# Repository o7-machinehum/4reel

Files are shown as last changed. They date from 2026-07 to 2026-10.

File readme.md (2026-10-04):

# 4reel
4reel is a platform for robots that don't have enough computing power to run machine vision algorithms. It's capable of stereo depth processing, image classification and SLAM.

When connected over USB-C the device will present itself as an Ethernet adapter and DHCP you an IP address, configuration can be done on the web portal at `http://192.168.77.1:8080/`

The JST connecter can be used to send data UART to an Arduino, ESP32, etc. The same JST conncetor can be used to power the device with 5V.
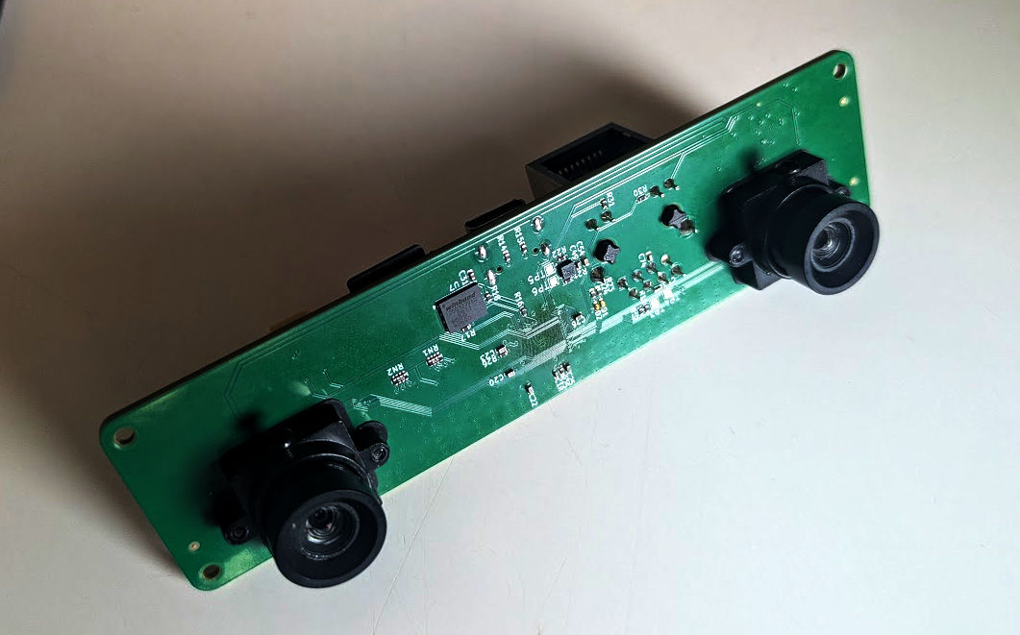
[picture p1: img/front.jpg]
Main image

## System Overview

4reel RV1103 board block diagram

## Repo structure
``` bash
.
|-- img
|-- os
|-- readme.md
|-- ref
|-- rv1103    # Current tested board
|-- rv1106    # Next generation
`-- scripts   # Automation scripts I wrote
```

# Media
- https://youtube.com/shorts/XkLzl0wEfN4?si=KPXePSXCayTTsI1j

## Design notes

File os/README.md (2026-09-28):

# 4reel OS

Buildroot-based Linux image for the 4reel boards (RV1103 and RV1106).

```sh
git submodule update --init
cd buildroot
make BR2_EXTERNAL=$PWD/../ rv1103g_defconfig
make
```

The SD-card image is written to `os/buildroot/output/images/sdcard.img`.

Linux and U-Boot use standalone configs in `board/rv1103g/{linux,uboot}_defconfig`.
After menuconfig changes, save them with `make linux-update-defconfig` or
`make uboot-update-defconfig`. Omit the machine-specific
`CONFIG_ENV_DEFAULT_ENV_TEXT_FILE` line from the saved U-Boot config; Buildroot
sets it from `uboot.env`.

The device-hosted camera dashboard is at `http://192.168.77.1:8080/`;
[calibration instructions](board/rv1103g/WEB_DEPTH.md) cover its first depth map.

On the RV1103G board, USB-C presents a network adapter to the host. The host
gets an address via DHCP; connect with `ssh root@192.168.77.1`. Root logs in
without a password in this development image.

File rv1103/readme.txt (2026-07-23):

Ovrdrive
--------
Size :	36.6 x 15 mm
Layer : 4 Layers
Material : FR-4: TG150
Thickness : 1.6 mm nominal (PCBWay regular 4-layer construction)
Min track/spacing : 4/4mil
Min hole size : 0.2mm
Solder mask : Black
Silkscreen : White
Edge connector : No
Surface finish : HASL lead free
Via process : Tenting vias
Finished copper : 1 oz Cu (Inner Copper:1 oz)
Remove product No. : Yes

PCBWay regular 4-layer stackup (nominal 1.6 mm)
-------------------------------------------------
Selected construction: PCBWay "4-layers PCB Regular" with 1 oz finished
outer copper and 1 oz inner copper.

Top to bottom:
L1 Cu : 0.5 oz base copper, plated to 1 oz finished (~0.035 mm)
PP    : 7628 RC46%, Dk 4.7, 0.1855 mm after lamination
L2 Cu : 1 oz (0.035 mm), continuous GND reference plane
Core  : Dk 4.6, 1.0300 mm dielectric (1.1 mm including L2/L3 copper)
L3 Cu : 1 oz (0.035 mm), continuous GND reference plane
PP    : 7628 RC46%, Dk 4.7, 0.1855 mm after lamination
L4 Cu : 0.5 oz base copper, plated to 1 oz finished (~0.035 mm)

PCBWay lists this construction at approximately 1.51 mm finished thickness,
with +/-10% tolerance, ordered as nominal 1.6 mm.

100 ohm differential Ethernet routing
--------------------------------------
Geometry: edge-coupled microstrip on L1/L4, referenced to the adjacent GND plane
Target differential impedance : 100 ohm +/-10%
Trace width                   : 0.160 mm (6.30 mil)
Pair gap, edge-to-edge         : 0.125 mm (4.92 mil)
Reference-plane height         : 0.1855 mm
Finished outer copper          : approximately 0.035 mm
Dielectric constant used       : 4.7

IPC/Wadell closed-form estimate without solder mask: approximately 101 ohm
differential. Solder mask, actual material properties, copper shape, and PCBWay
process compensation are not included in that estimate. Order the PCB with
100 ohm differential impedance control and allow PCBWay to adjust the production
width/gap after their field-solver review.

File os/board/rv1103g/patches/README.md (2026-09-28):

# Pending upstream support

Buildroot applies these queues through `BR2_GLOBAL_PATCH_DIR`, in filename
order, after extracting each source tree.

## Linux

The pinned Rockchip 6.1 source already contains the RV1103/RV1106 clock,
pinctrl, and device-tree support. The Linux patch queue only adds board-required
behavior missing from that vendor tree. `linux/linux.hash` verifies the pinned
source archive and its license files.

The board patches make the left-camera rotation persistent and make CIF scale
capture start its sensor/CSI source without full-resolution memory DMA.
RV1103/RV1106 has one shared scaler: the left camera uses it; the right camera
uses normal CSI capture and software downsampling. Both sensors use VC0 on
their separate CSI receivers.
The CMA heap patch supplies the physical-address query and cache synchronization
needed by the RVE SAD backend; physical-address access requires root privileges.

## U-Boot

The U-Boot queue is the complete 15-patch v3 submission with cover
Message-ID `20260707153135.2048115-1-sjg@chromium.org`. It applies to exact
base commit:

```text
ee5d46b45ec0c63f8f9dd1e816e0dac3452ccc3d
```

Keeping the full series preserves the dependencies between the early RV1103B
patches and the later RV1106/RV1103 changes. The RV1103G board DTS, default
environment, and standalone `uboot_defconfig` configure 4reel without loading
the Luckfox defconfig or modifying the submitted patches. The existing
`CONFIG_TARGET_LUCKFOX_PICO_RV1103` selection supplies the shared 64 MiB board
initialization code; the device tree and boot environment are 4reel's.

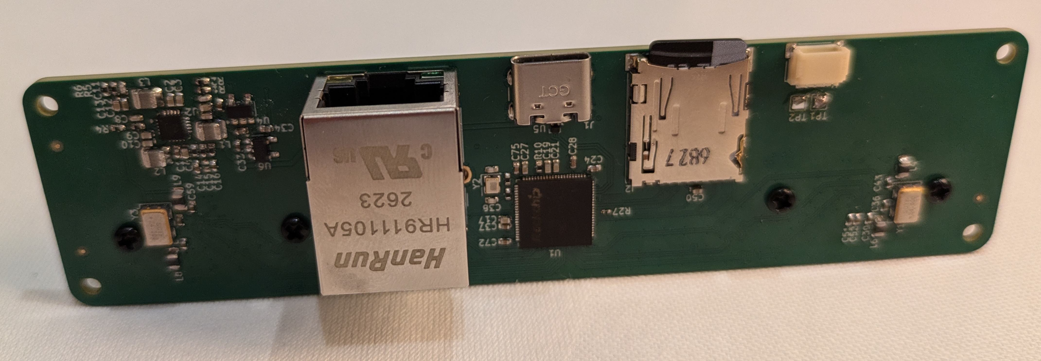
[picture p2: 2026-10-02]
img/back.jpg

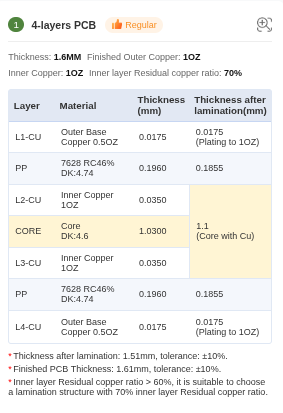
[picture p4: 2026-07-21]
rv1106/stackup.png

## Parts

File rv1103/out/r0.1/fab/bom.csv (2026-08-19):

Designator | Value | Footprint | Quantity | Part Number
C1,C14,C16,C18,C24,C28,C31,C36,C37,C41,C42,C45,C49,C51-C53,C61-C63,C66-C68,C70,C72,C75 | 100nF | Capacitor_SMD:C_0402_1005Metric | 25 | CL05B104KP5VPNC
C2-C5,C7,C9,C10,C12,C13,C17,C19-C23,C25-C27,C50,C54 | 10uF | Capacitor_SMD:C_0402_1005Metric | 20 | GRM155R60J106ME05D
C6,C8,C11 | 220pF | Capacitor_SMD:C_0402_1005Metric | 3 | GCM1555C1H221JA16D
C29,C30,C33-C35,C39,C40,C43,C44,C46-C48,C55-C60,C64,C65,C69,C71 | 1uF | Capacitor_SMD:C_0402_1005Metric | 22 | C0402C105K9PACTU
C32,C38 | 10pF | Capacitor_SMD:C_0402_1005Metric | 2 | GCM1555C1H100JA16D
C73,C74 | 10nF | Capacitor_SMD:C_0402_1005Metric | 2 | C0402C103K5REC7411
D1,D2 | LED | LED_SMD:LED_0402_1005Metric | 2 | LTST-C281KGKT
J1 | USB_C_Receptacle_USB2.0_16P | Connector_USB:USB_C_Receptacle_GCT_USB4105-xx-A_16P_TopMnt_Horizontal | 1 | USB4105-GF-A-120
J2 | Micro_SD_Card_Det2 | Connector_Card:microSD_HC_Hirose_DM3AT-SF-PEJM5 | 1 | DM3AT-SF-PEJM5
J3 | RJ45_Hanrun_HR911105A_Horizontal | Connector_RJ:RJ45_Hanrun_HR911105A_Horizontal | 1 | HR911105A
J4 | JST | Connector_JST:JST_SH_SM04B-SRSS-TB_1x04-1MP_P1.00mm_Horizontal | 1 | SM04B-SRSS-TB
L1-L3 | 1.5uH | Inductor_SMD:L_1008_2520Metric | 3 | DFE252012P-1R5M=P2
L4-L9 | 3u3/0.9A | Inductor_SMD:L_0805_2012Metric | 6 | MLP2012S3R3MT0S1
R1 | 40.2k | Resistor_SMD:R_0402_1005Metric | 1 | RC0402FR-0740K2L
R2 | 9.1k | Resistor_SMD:R_0402_1005Metric | 1 | RC0402FR-079K1L
R3 | 47k | Resistor_SMD:R_0402_1005Metric | 1 | RC0402FR-0747KL
R4,R6,R9 | 100k | Resistor_SMD:R_0402_1005Metric | 3 | RC0402FR-07100KL
R5,R7 | 200k | Resistor_SMD:R_0402_1005Metric | 2 | RC0402FR-07200KL
R8,R17,R18,R26 | 10k | Resistor_SMD:R_0402_1005Metric | 4 | RC0402FR-0710KL
R10 | 240R | Resistor_SMD:R_0402_1005Metric | 1 | RC0402FR-07240RL
R11,R12,R21,R22 | 4.7k | Resistor_SMD:R_0402_1005Metric | 4 | RC0402FR-074K7L
R13,R32 | 0R | Resistor_SMD:R_0402_1005Metric | 2 | RC0402FR-070RL
R14,R15 | 5.6k | Resistor_SMD:R_0402_1005Metric | 2 | RC0402FR-075K6L
R16,R19 | 22R | Resistor_SMD:R_0402_1005Metric | 2 | RC0402FR-0722RL
R20 | 1M | Resistor_SMD:R_0402_1005Metric | 1 | RC0402FR-071ML
R23,R24 | 1k | Resistor_SMD:R_0402_1005Metric | 2 | RC0402FR-071KL
R25 | 6.04k | Resistor_SMD:R_0402_1005Metric | 1 | RC0402FR-076K04L
R27 | 22R | Resistor_SMD:R_0201_0603Metric | 1 | RC0201FR-0722RL
R30,R31 | 330R | Resistor_SMD:R_0402_1005Metric | 2 | RC0402FR-07330RL
RN1,RN2 | 47k | Resistor_SMD:R_Array_Concave_4x0402 | 2 | CAT10-473J4LF
TP3-TP6 | TestPoint | TestPoint:TestPoint_Pad_1.0x1.0mm | 4
U1 | RV1103G | rv1103b:Rockchip_QFN-88-1EP_9x9mm_P0.35mm_EP6.5x6.5mm | 1 | RV1103BG3
U2 | EA3036C | Package_DFN_QFN:QFN-20-1EP_3x3mm_P0.4mm_EP1.65x1.65mm | 1 | EA3036CQBR
U3,U9 | ImageSensor_OV9281 | ov9281:OV9281 | 2 | OV9281
U4 | TLV73312PDBV | Package_TO_SOT_SMD:SOT-23-5 | 1 | TLV73312PDBV
U5 | TPD2EUSB30 | Package_TO_SOT_SMD:Texas_DRT-3 | 1 | TPD2EUSB30ADRTR
U6 | TLV73328PDBV | Package_TO_SOT_SMD:SOT-23-5 | 1 | TLV73328PDBVR
U7 | W25Q32JVZP | Package_SON:WSON-8-1EP_6x5mm_P1.27mm_EP3.4x4.3mm | 1 | W25Q32JVZPIQ
U8 | LIS2HH12 | Package_LGA:LGA-12_2x2mm_P0.5mm | 1 | LIS2HH12TR
Y1,Y3 | TXC-7C | Oscillator:Oscillator_SMD_TXC_7C-4Pin_5.0x3.2mm | 2 | SX5M24.000D20F30TNN
Y2 | 24Mhz | Crystal:Crystal_SMD_2016-4Pin_2.0x1.6mm | 1 | ECS-240-8-37B-CKY-TR

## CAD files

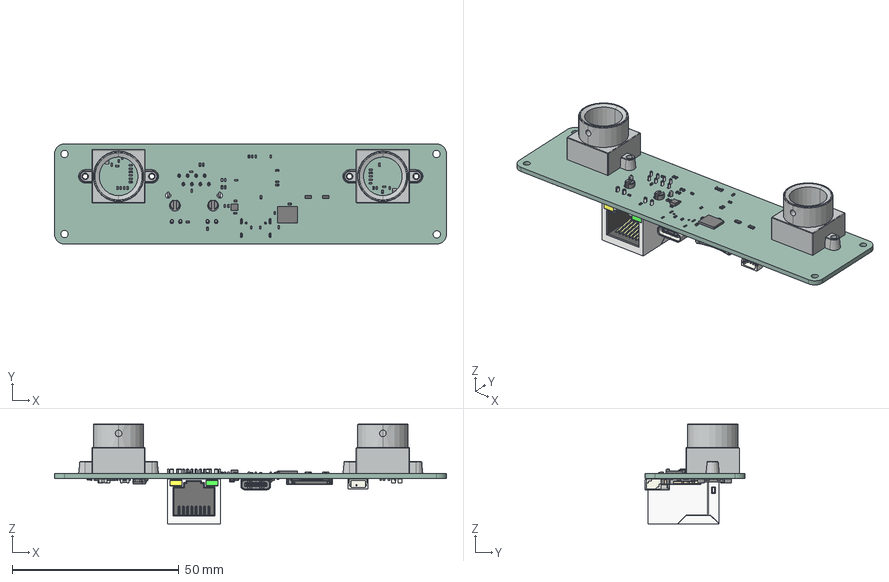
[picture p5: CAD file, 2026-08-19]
rv1103/out/r0.1/4reel_ee.step
117.5 x 30.0 x 29.9 mm
C_0402_1005Metric x 75
R_0402_1005Metric x 29
R_Array_Concave_4x0402 x 2
WSON-8-1EP_6x5mm_P1.27mm_EP3.4x4.3mm
LED_0402_1005Metric x 2
L_0805_2012Metric x 6
LGA_12_2x2mm_P05mm
M12 lens holder x 2
UQFN-20-1EP_3x3mm_Pitch0.4mm
C9D27868-9601-4F3A-8DEA-EF1FE52F23CF
L_1008_2520Metric x 3
SOT-23-5 x 2
R_0201_0603Metric
39AA0248-C475-4DC6-9496-78D43884E41A
Crystal_SMD_2016-4Pin_2.0x1.6mm
USB_C_Receptacle_16P_TopMnt_Horizontal_GCT_USB4105-xx-A
DRT_3
microSD_HC_Hirose_DM3AT-SF-PEJM5
JST_SH_SM04B-SRSS-TB_1x04-1MP_P1.00mm_Horizontal
4reel_ee_PCB

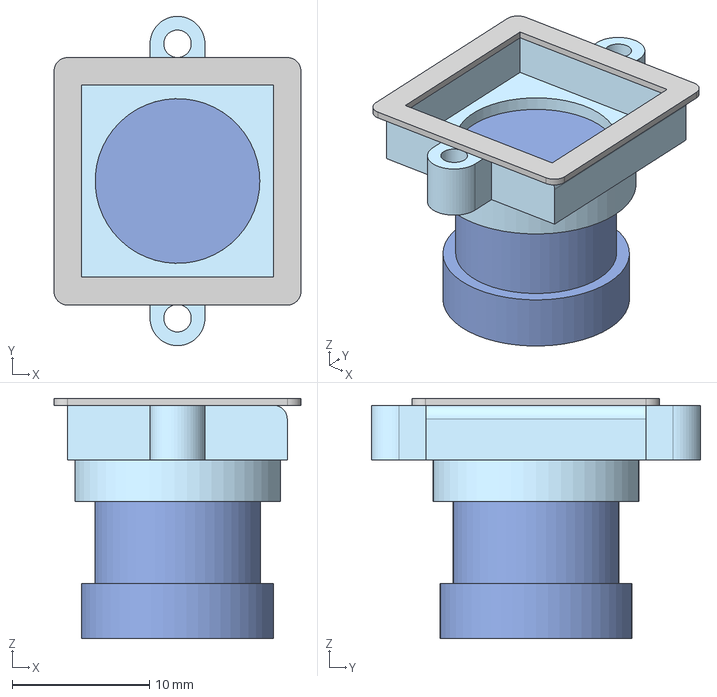
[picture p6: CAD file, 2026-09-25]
rv1103/step/Arducam_U0756.step
18.0 x 24.0 x 17.5 mm

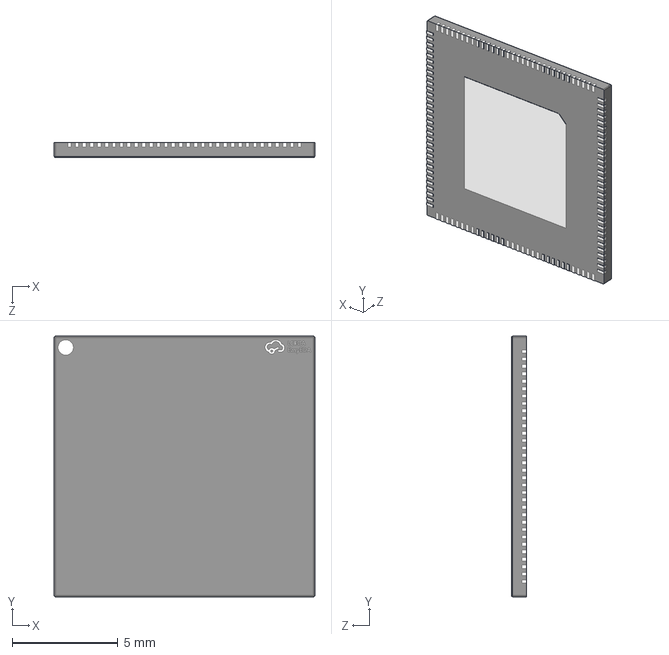
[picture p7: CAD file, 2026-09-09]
rv1106/step/QFN-128_L12.3-W12.3-P0.35-TL-EP7.0-1.step
12.3 x 12.3 x 0.73 mm

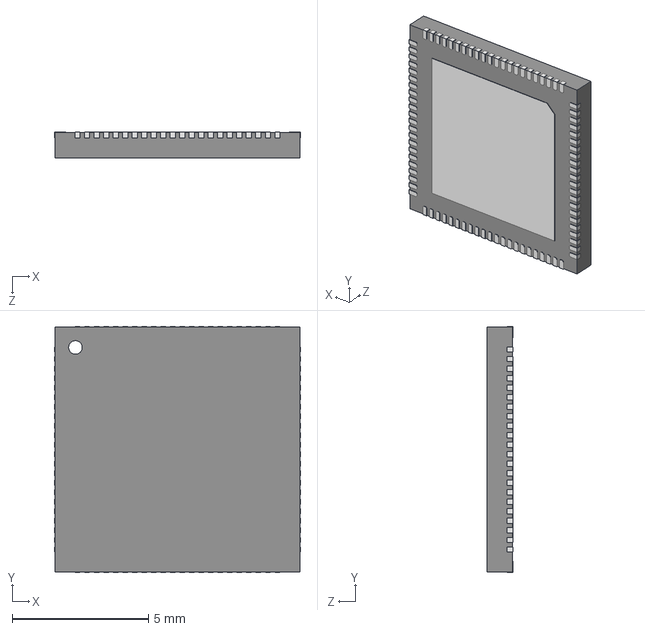
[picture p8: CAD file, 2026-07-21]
rv1106/step/QFN-88P35_EP.step
9.04 x 9.04 x 0.97 mm

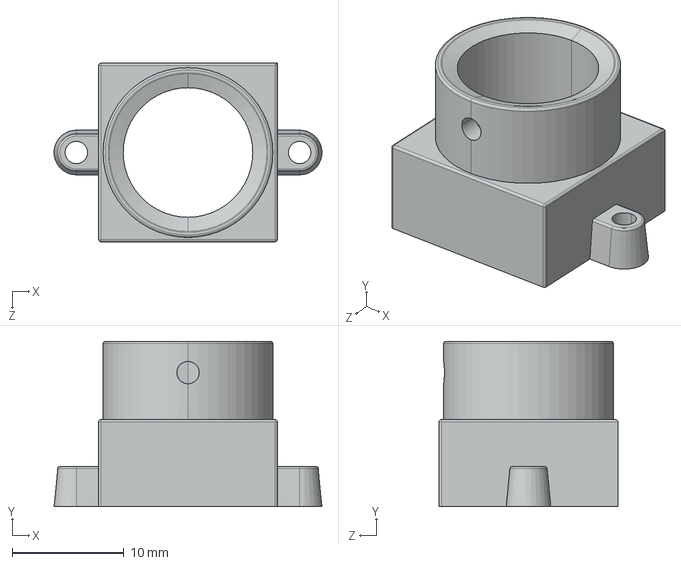
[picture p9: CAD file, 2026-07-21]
rv1103/step/M12_lens_holder.STEP
24.0 x 14.8 x 16.0 mm

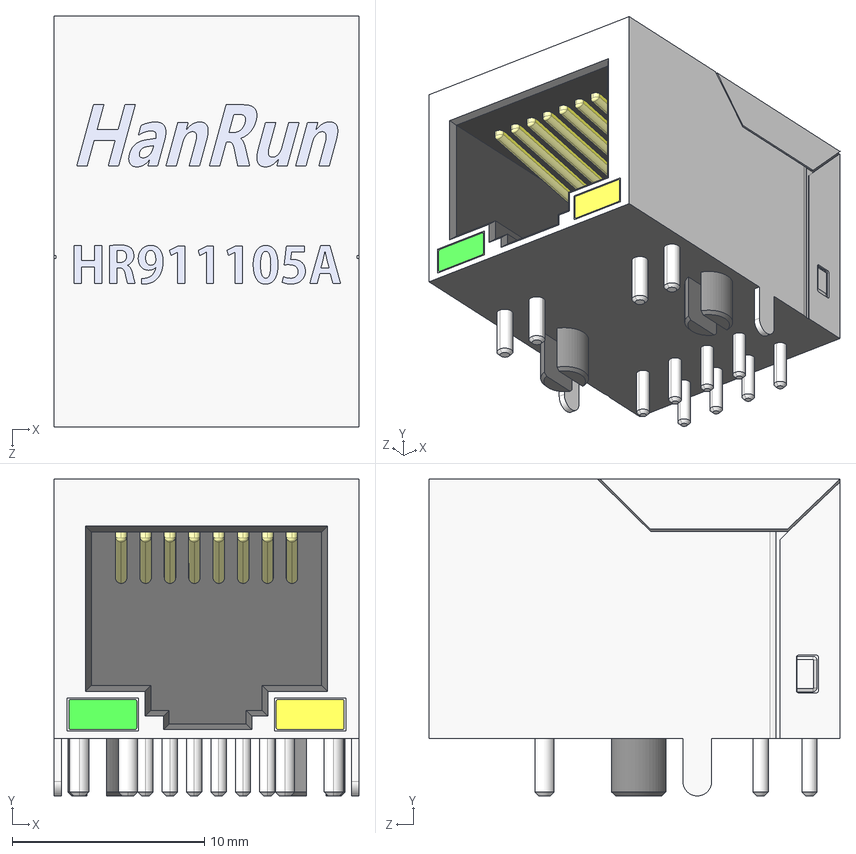
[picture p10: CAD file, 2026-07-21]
rv1106/step/HR911105A.step
15.9 x 16.5 x 21.4 mm

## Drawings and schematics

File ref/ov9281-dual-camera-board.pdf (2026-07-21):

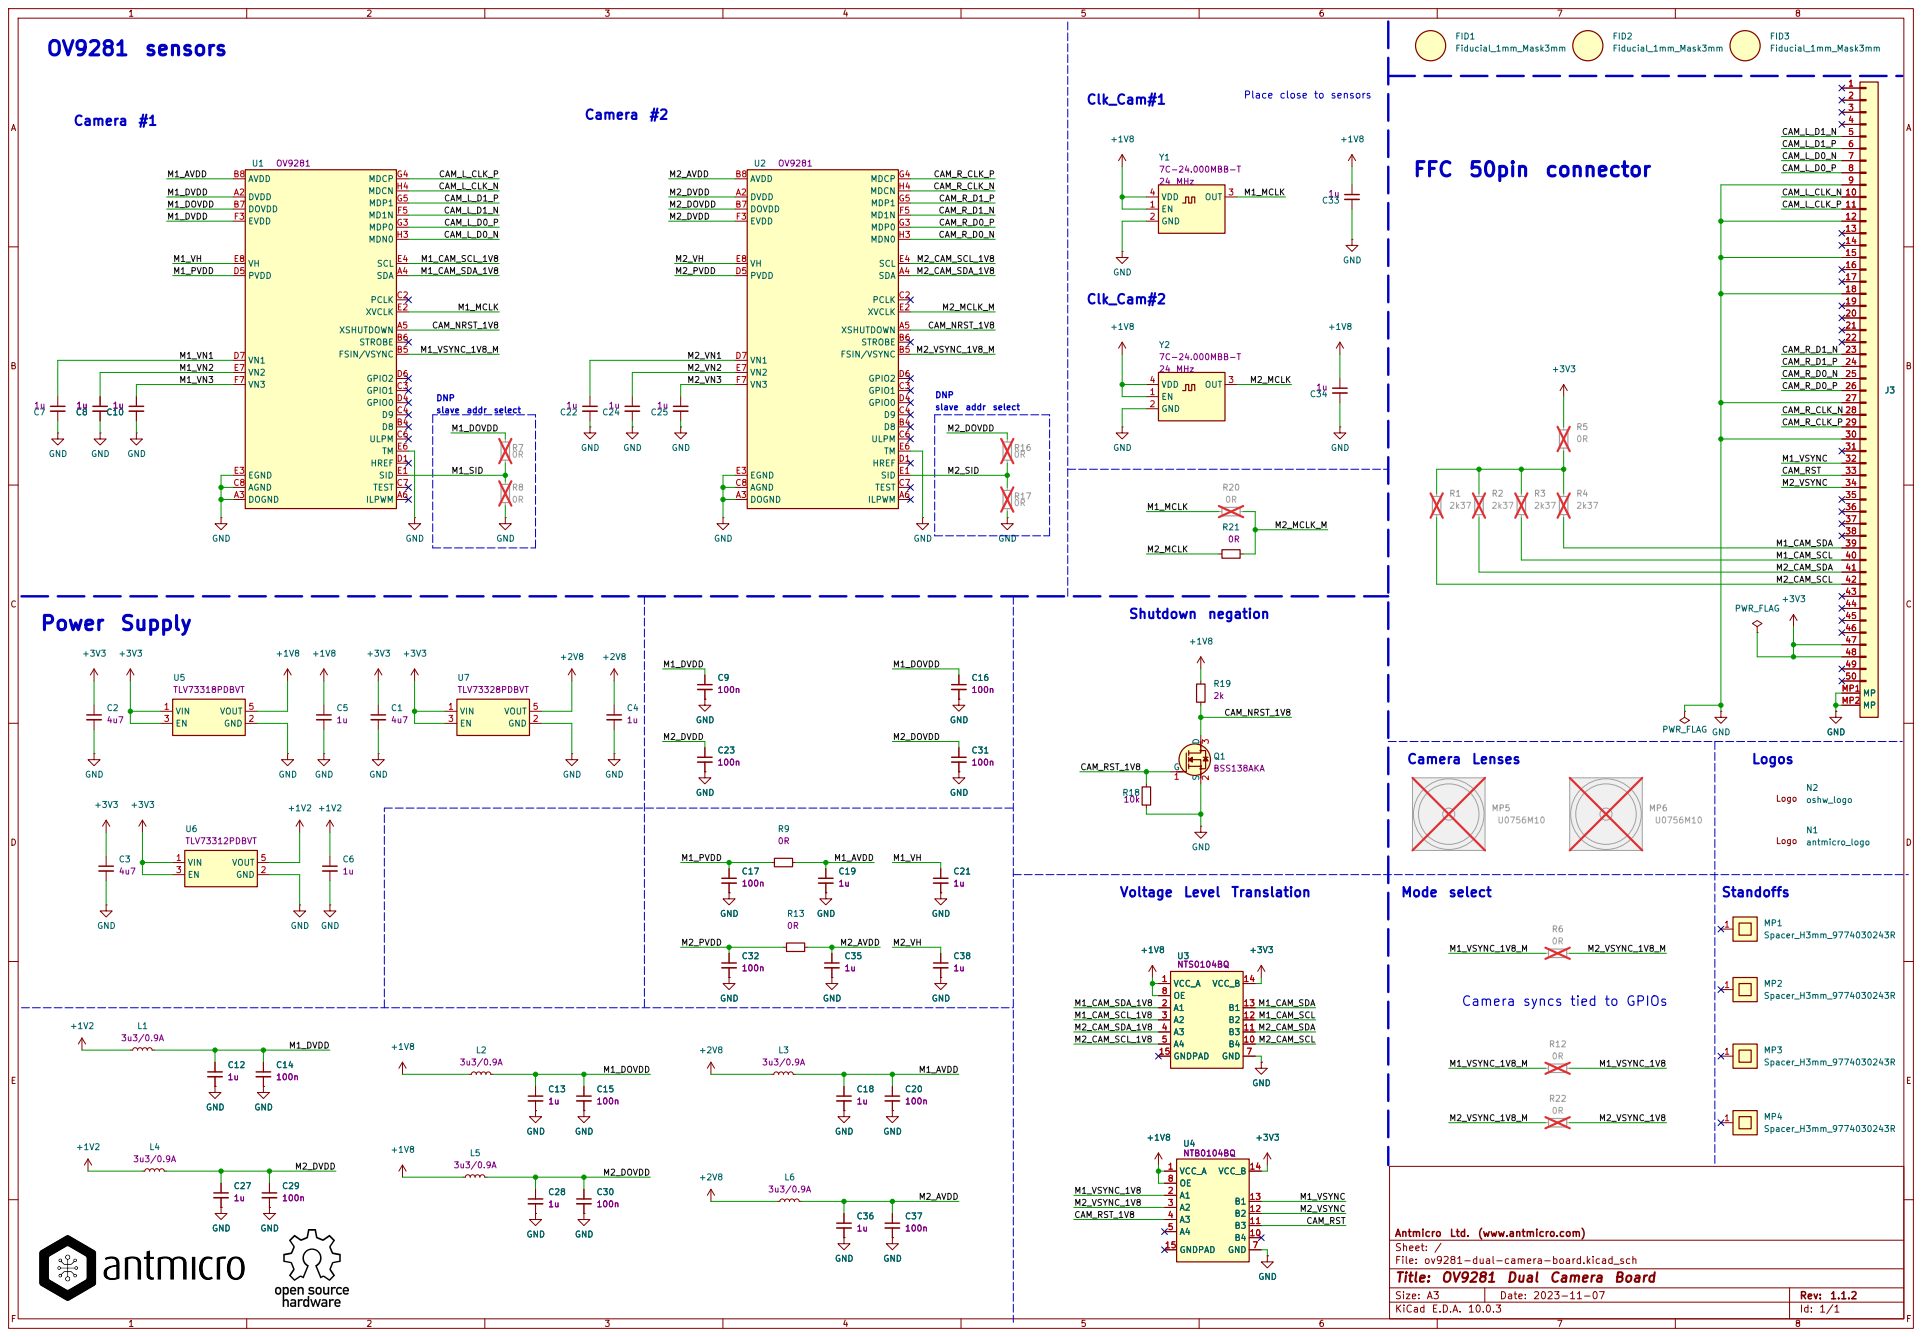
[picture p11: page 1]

Place close to sensors

DVDD A2 DOGND A3
FSIN/VSYNC B5 STROBE B6 DOVDD B7

J3 DVDD A2 DOGND A3

Shutdown negation Power Supply

Camera syncs tied to GPIOs

Antmicro Ltd. (www.antmicro.com) GND

Sheet: /
File: ov9281-dual-camera-board.kicad_sch
Title: OV9281 Dual Camera Board

Size: A3 | Rev: 1.1.2 | F Date: 2023-11-07
KiCad E.D.A. 10.0.3 | Id: 1/1

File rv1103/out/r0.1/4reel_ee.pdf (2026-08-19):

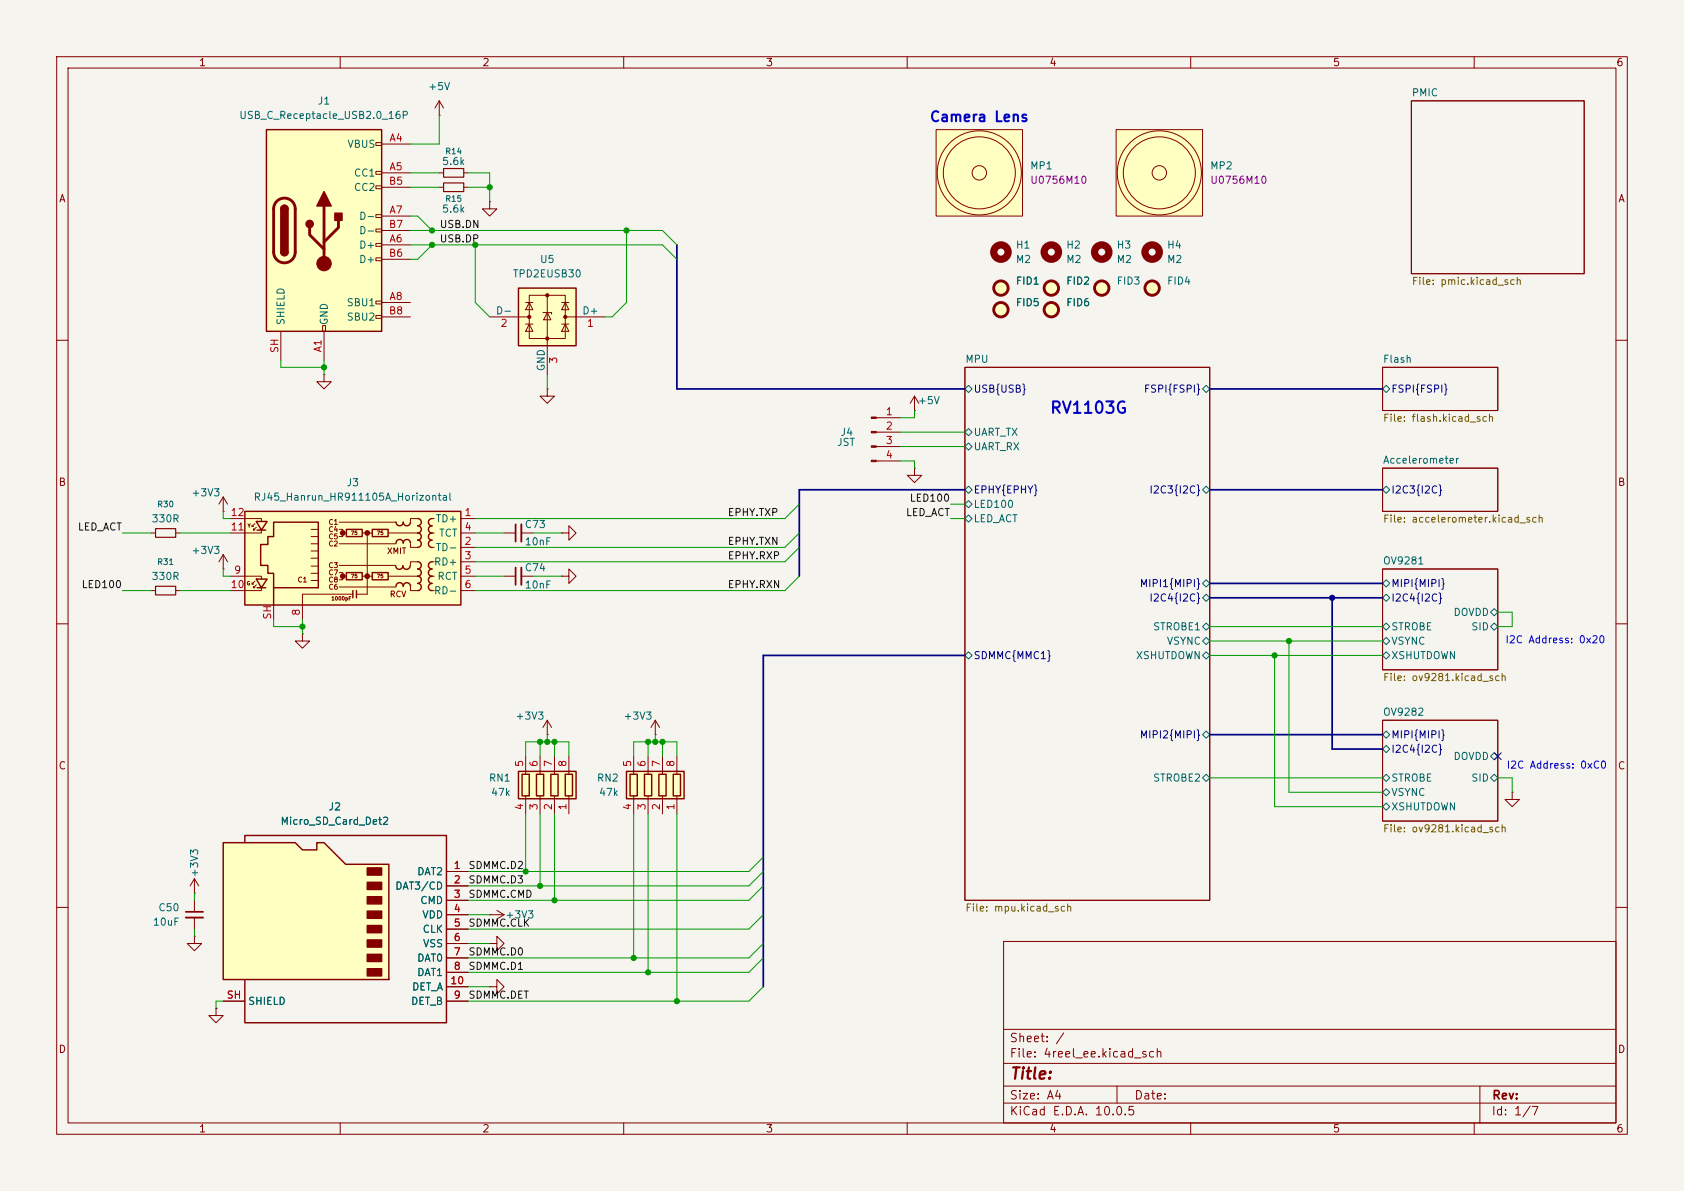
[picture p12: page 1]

I2C3{I2C} Accelerometer File: accelerometer.kicad_sch PMIC

Size: A4 | Rev:
KiCad E.D.A. 10.0.5 | Id: 1/7

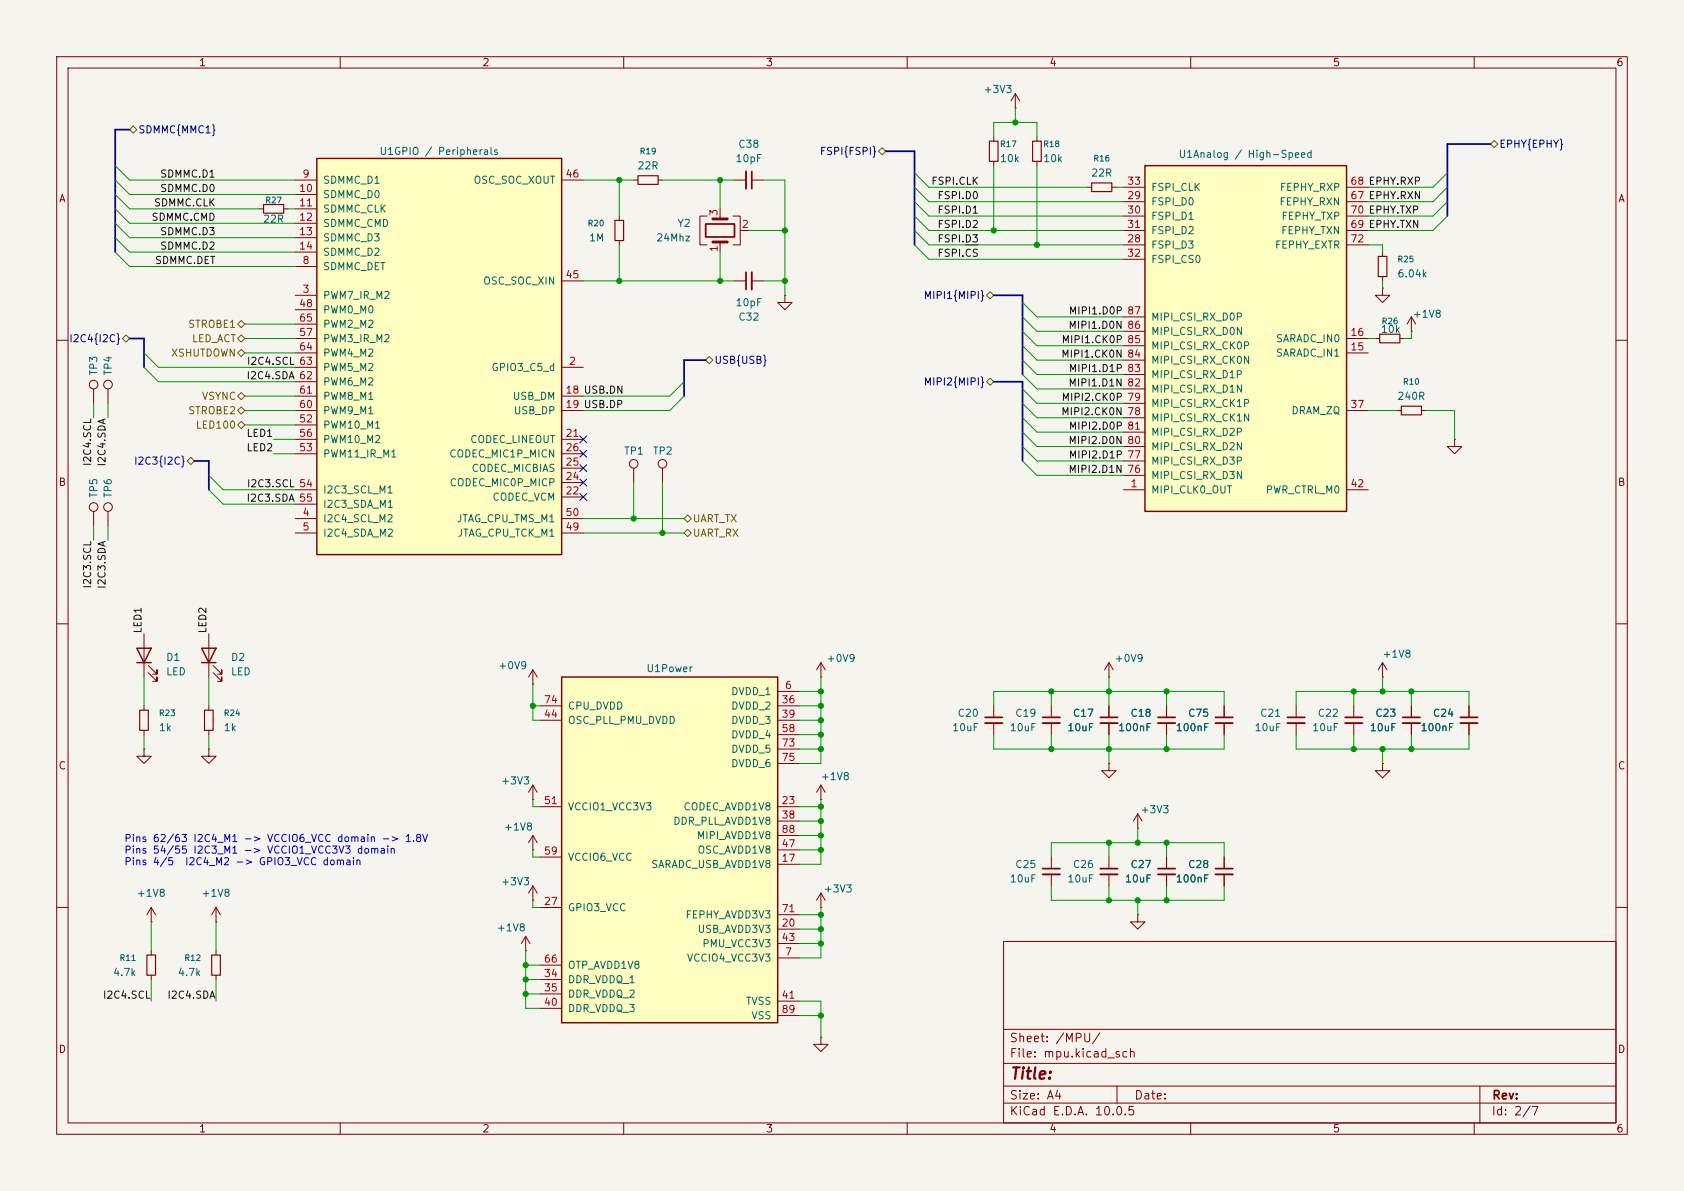
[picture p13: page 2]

SDMMC.DET SDMMC.CLK
SDMMC.CMD

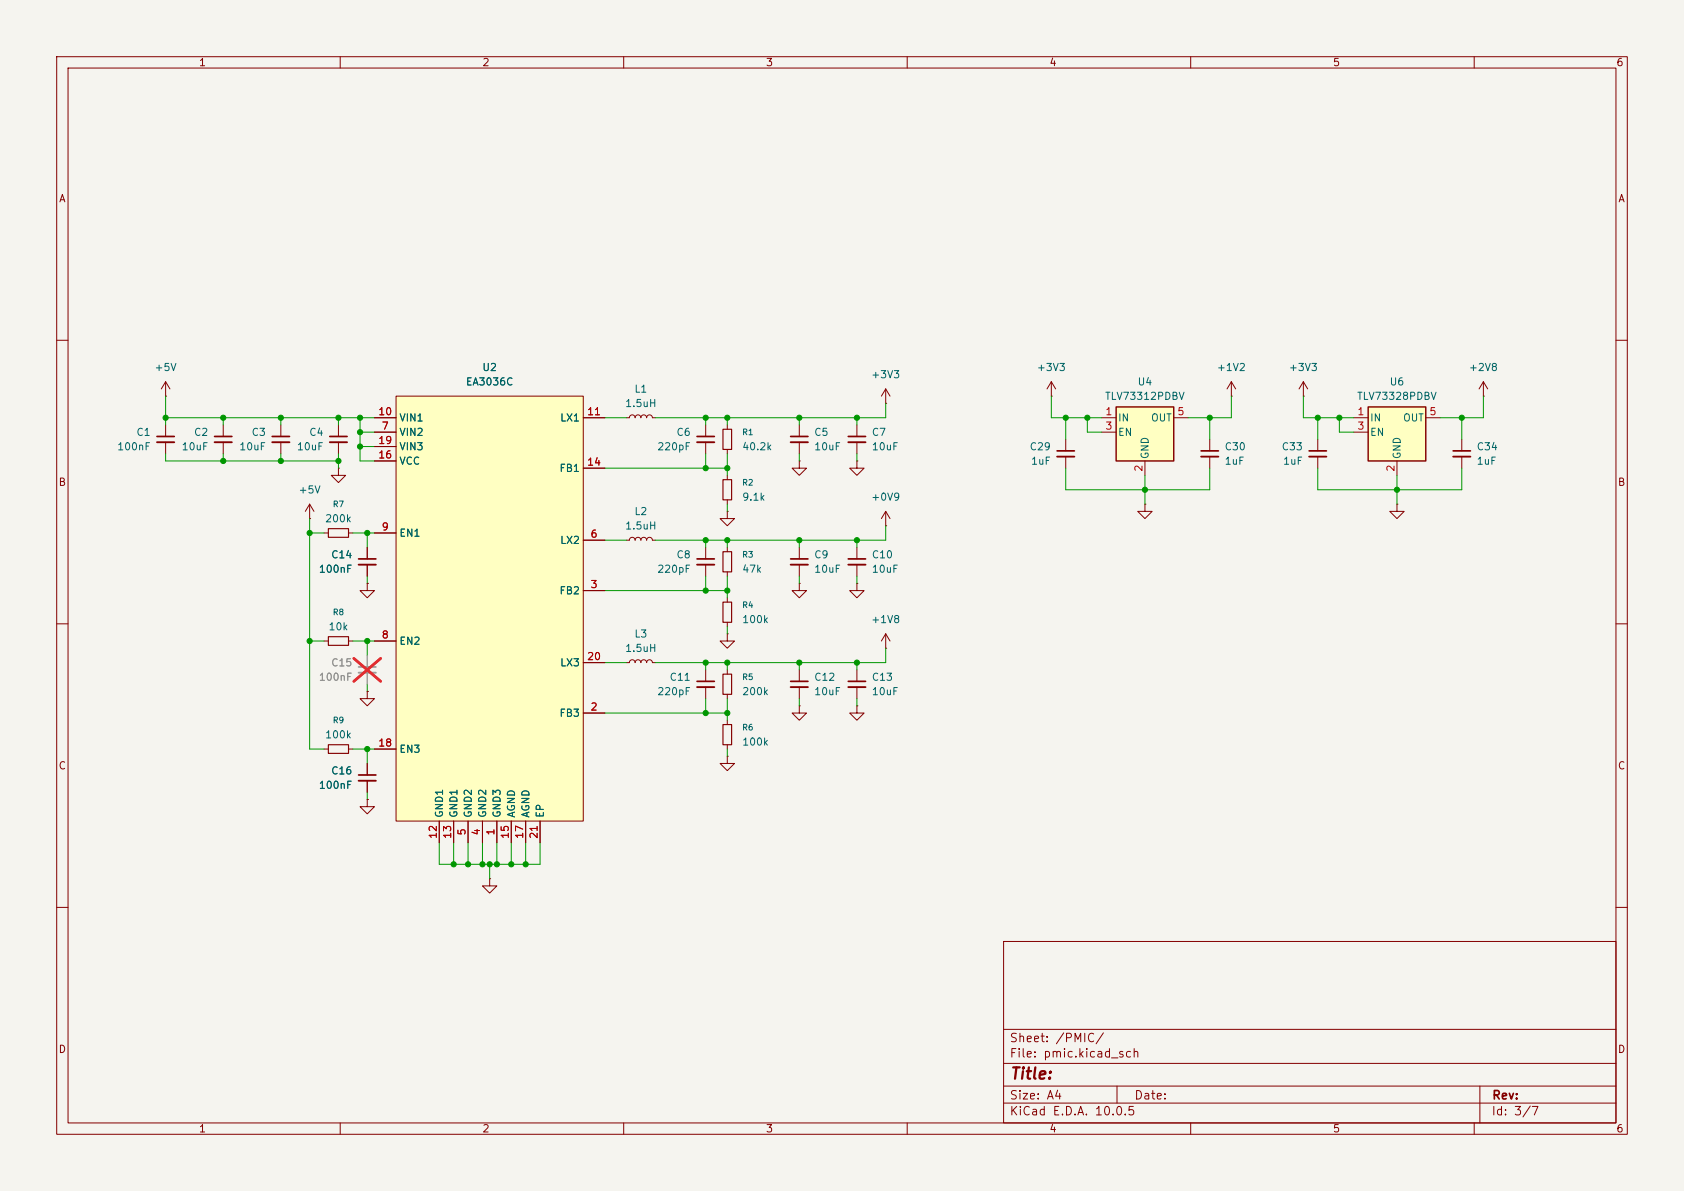
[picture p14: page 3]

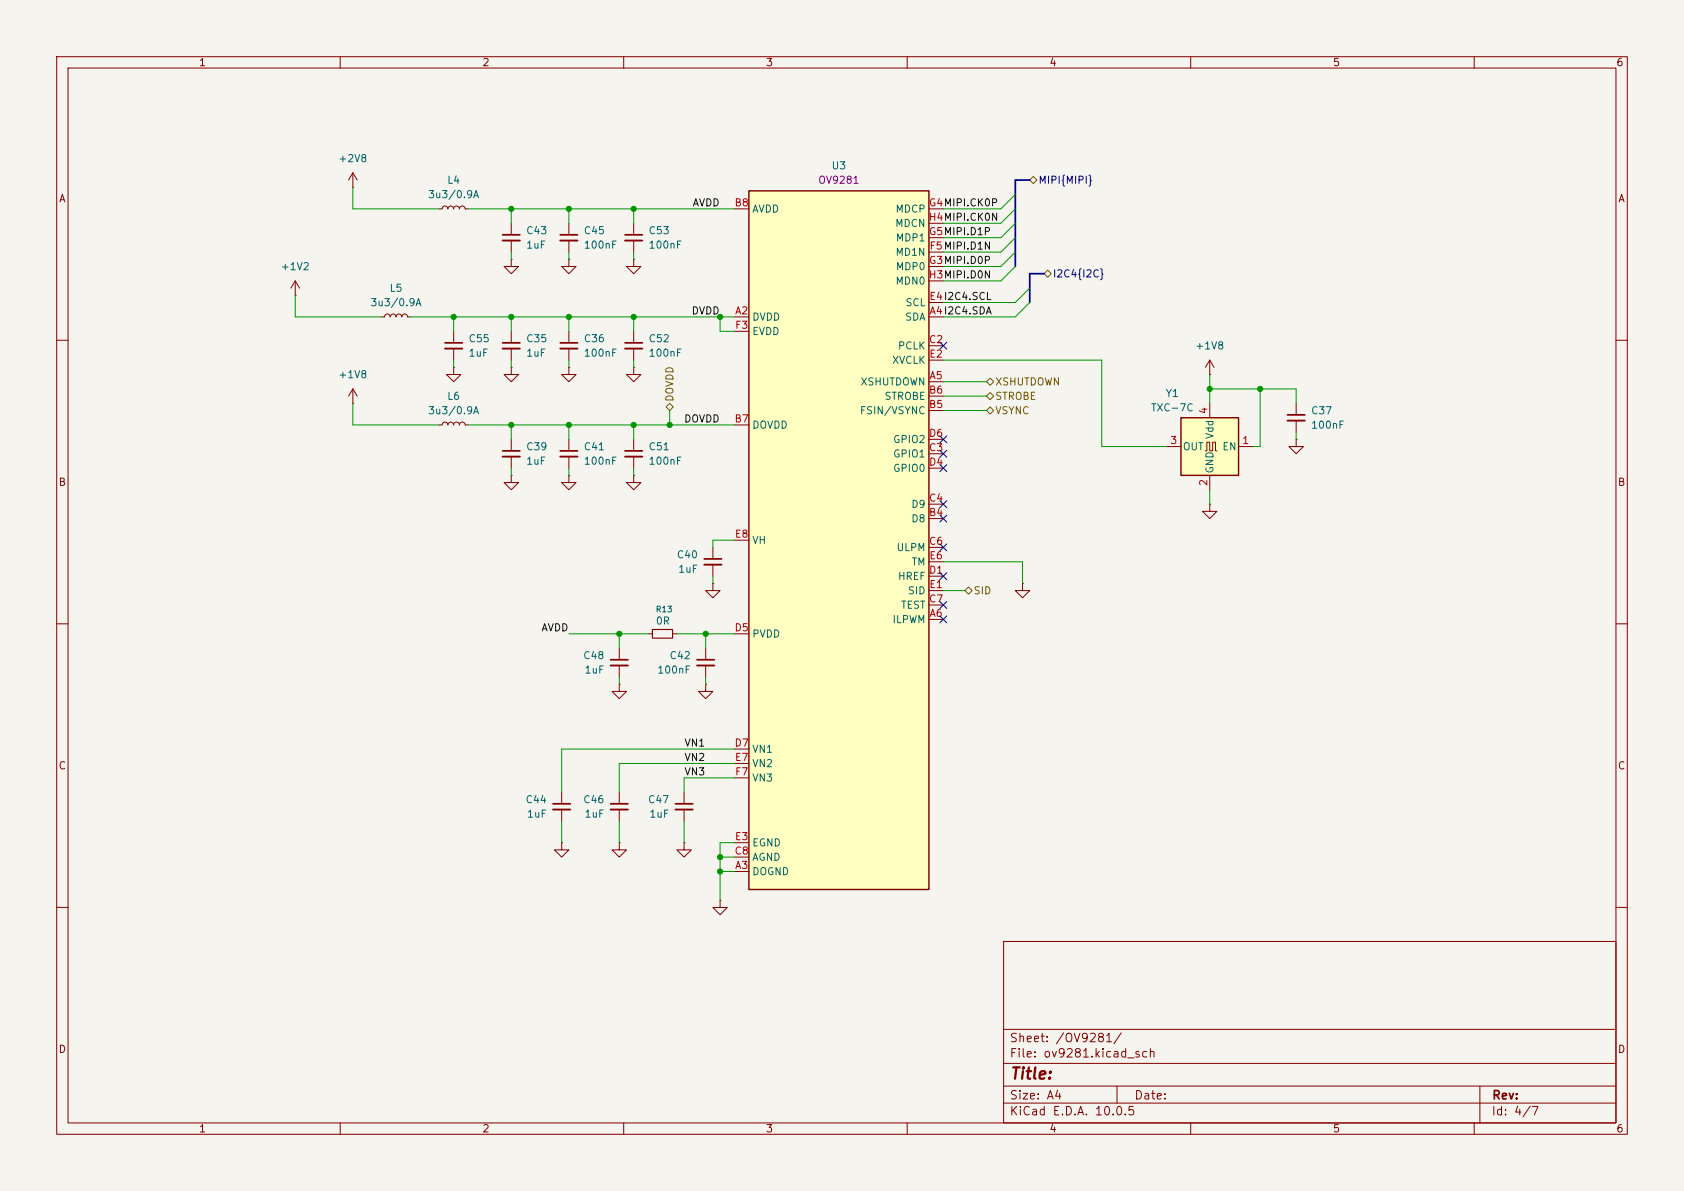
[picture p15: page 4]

I2C4.SCL MIPI.D1N MIPI.D0P MIPI.CK0N MIPI.D0N

FSIN/VSYNC B5 STROBE B6 DOVDD B7

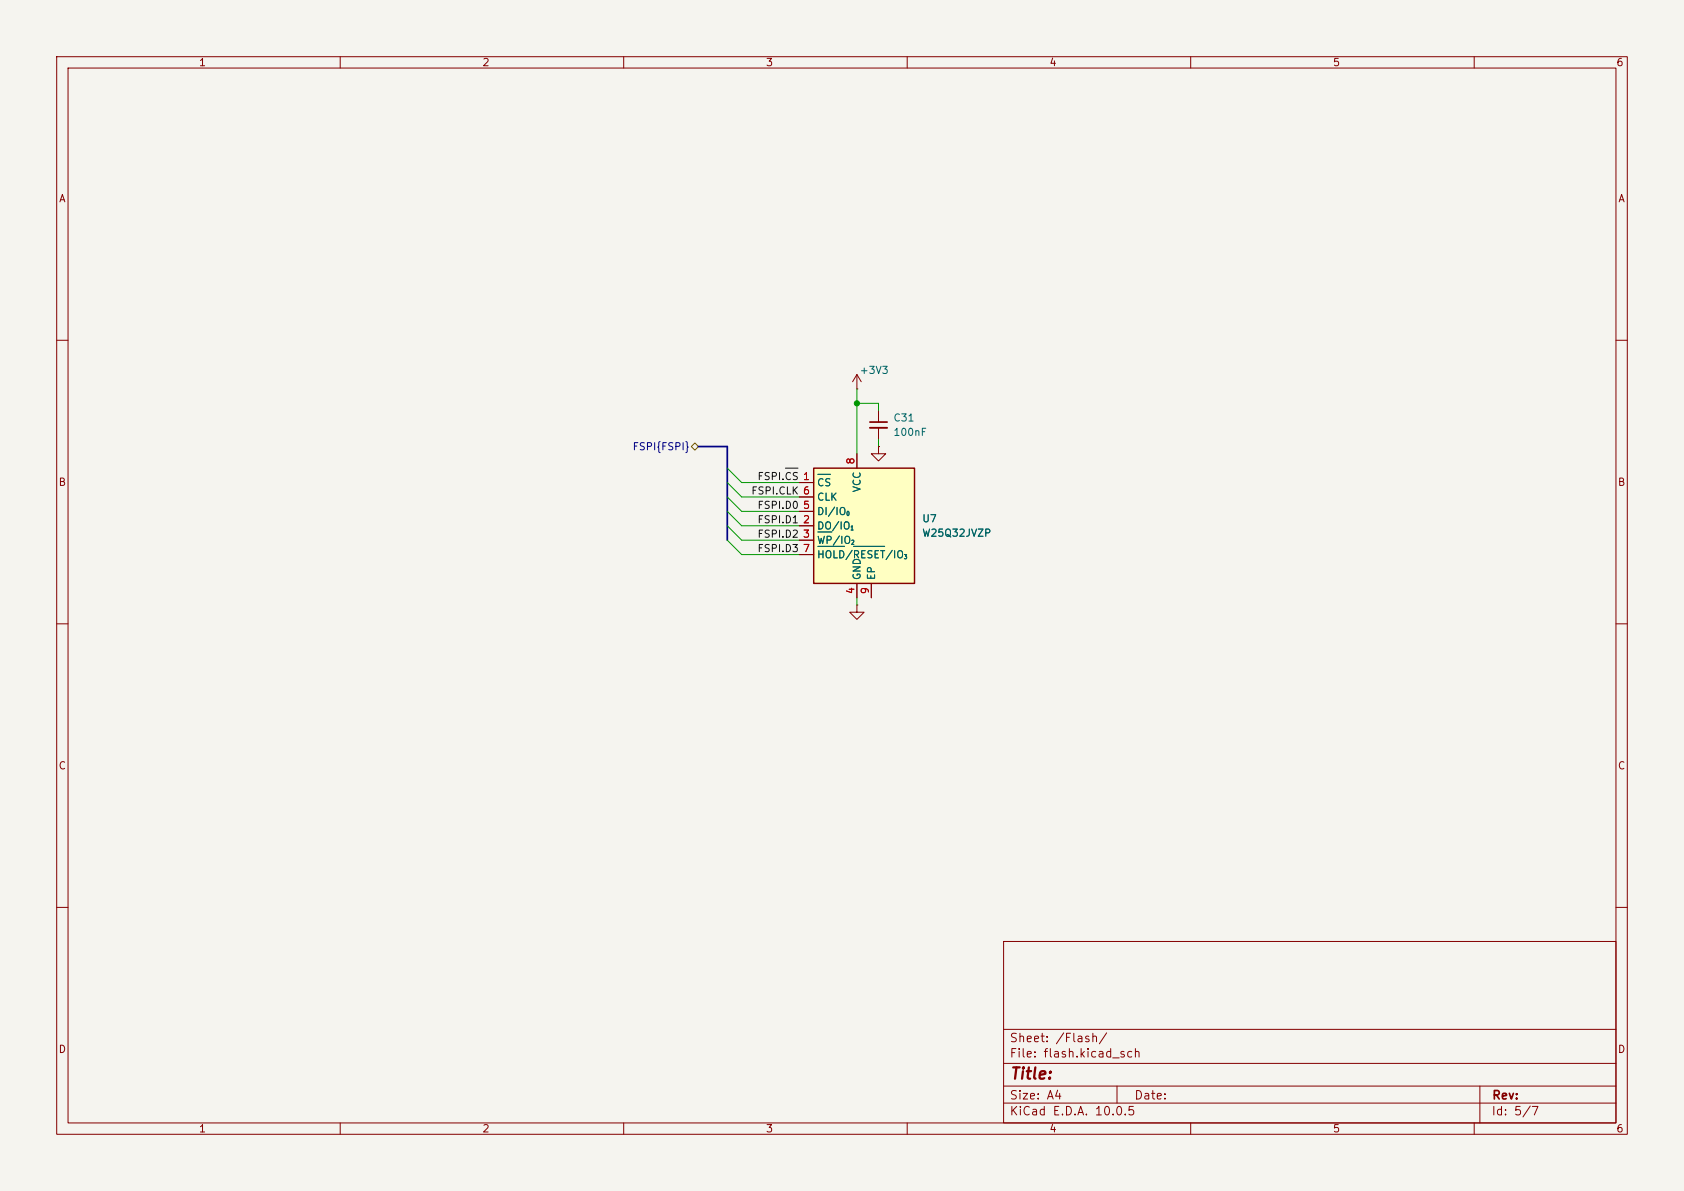
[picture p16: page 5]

4 DI/IO0 5 CLK 6 HOLD/RESET/IO3 7 VCC

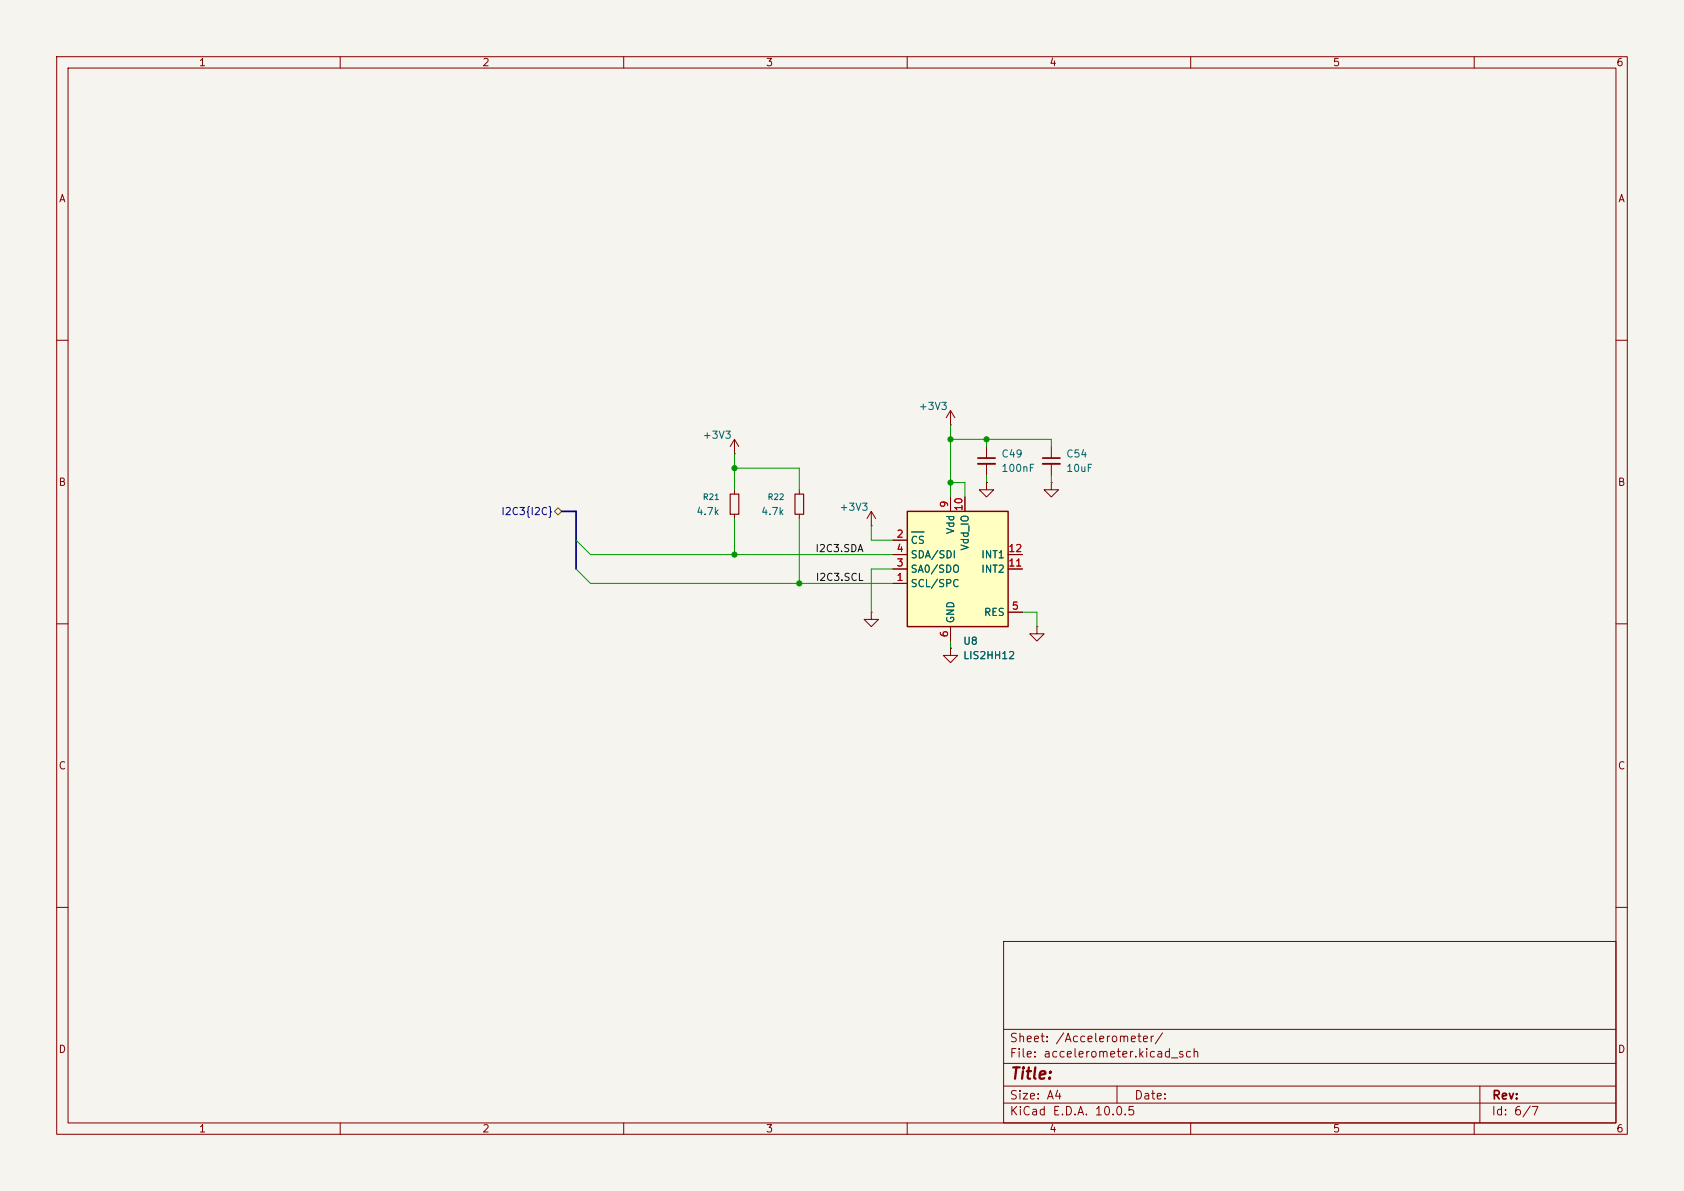
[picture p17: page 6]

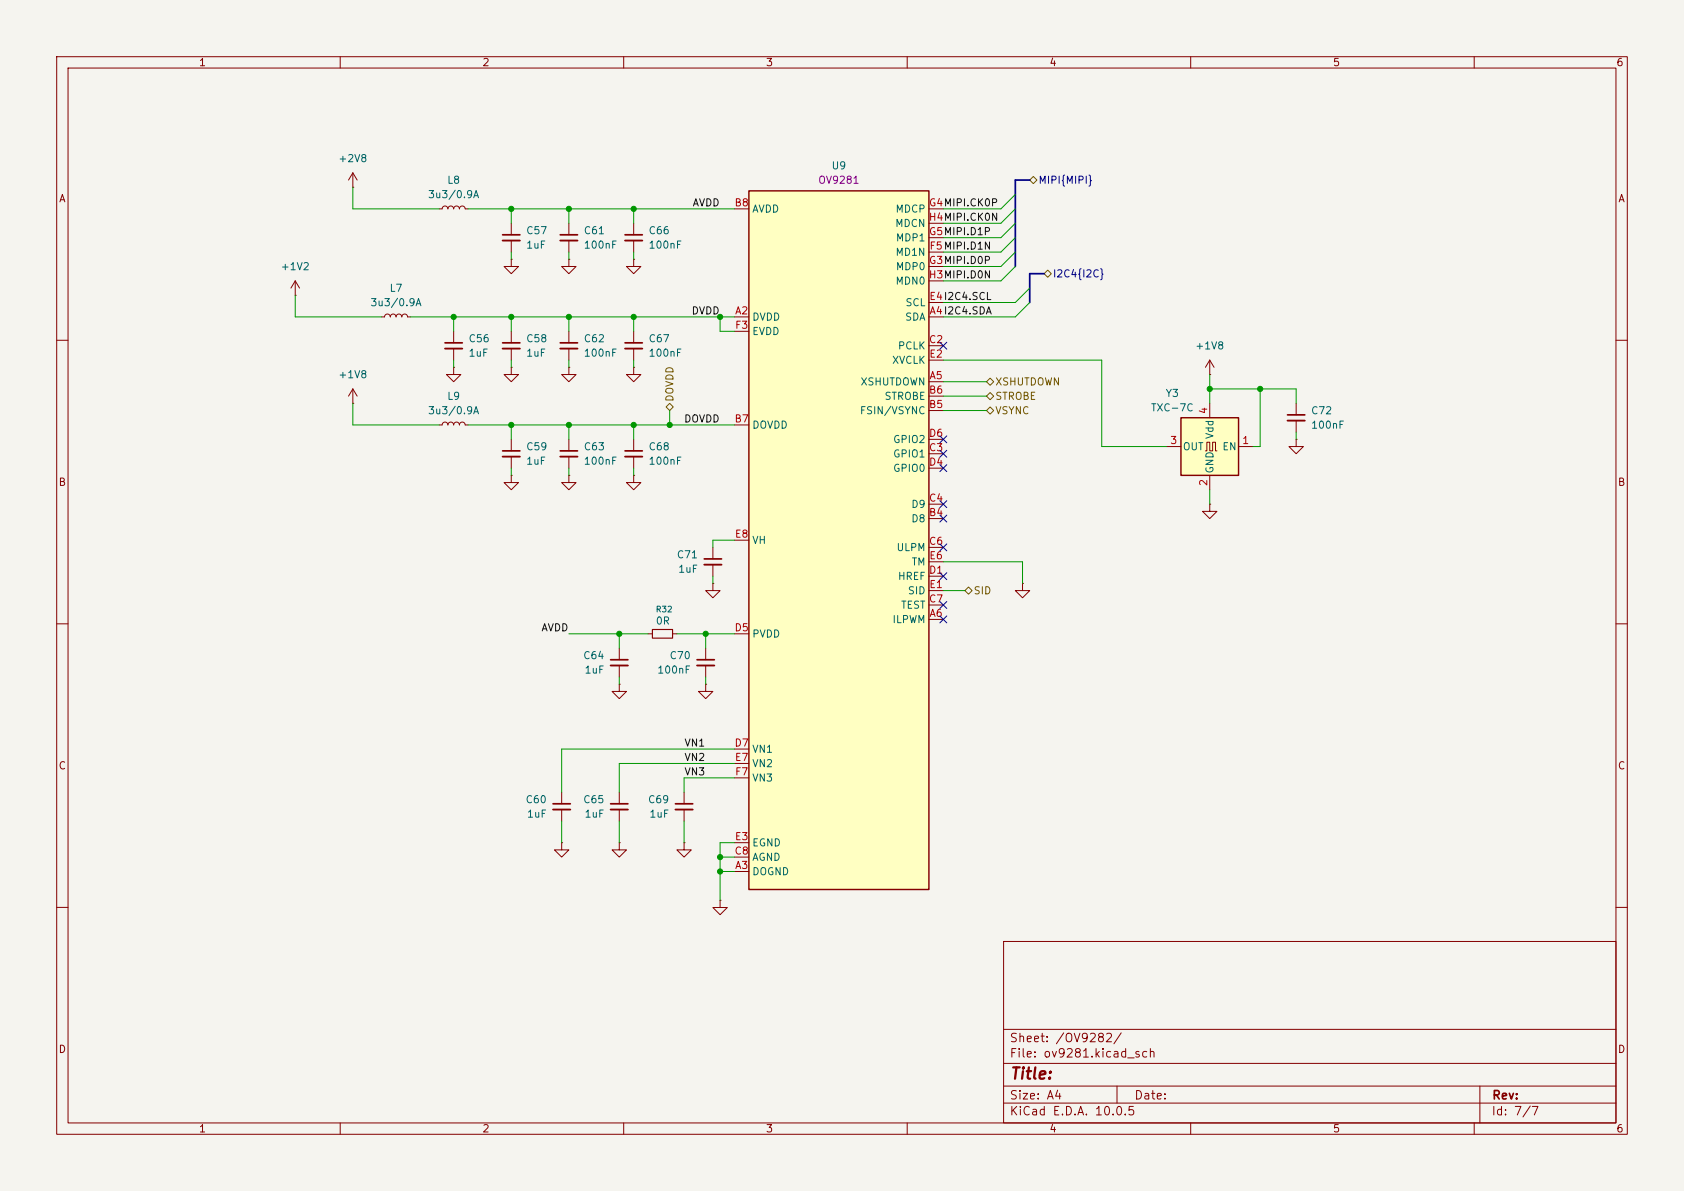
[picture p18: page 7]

I2C4.SCL MIPI.D1N MIPI.D0P MIPI.CK0N MIPI.D0N

FSIN/VSYNC B5 STROBE B6 DOVDD B7

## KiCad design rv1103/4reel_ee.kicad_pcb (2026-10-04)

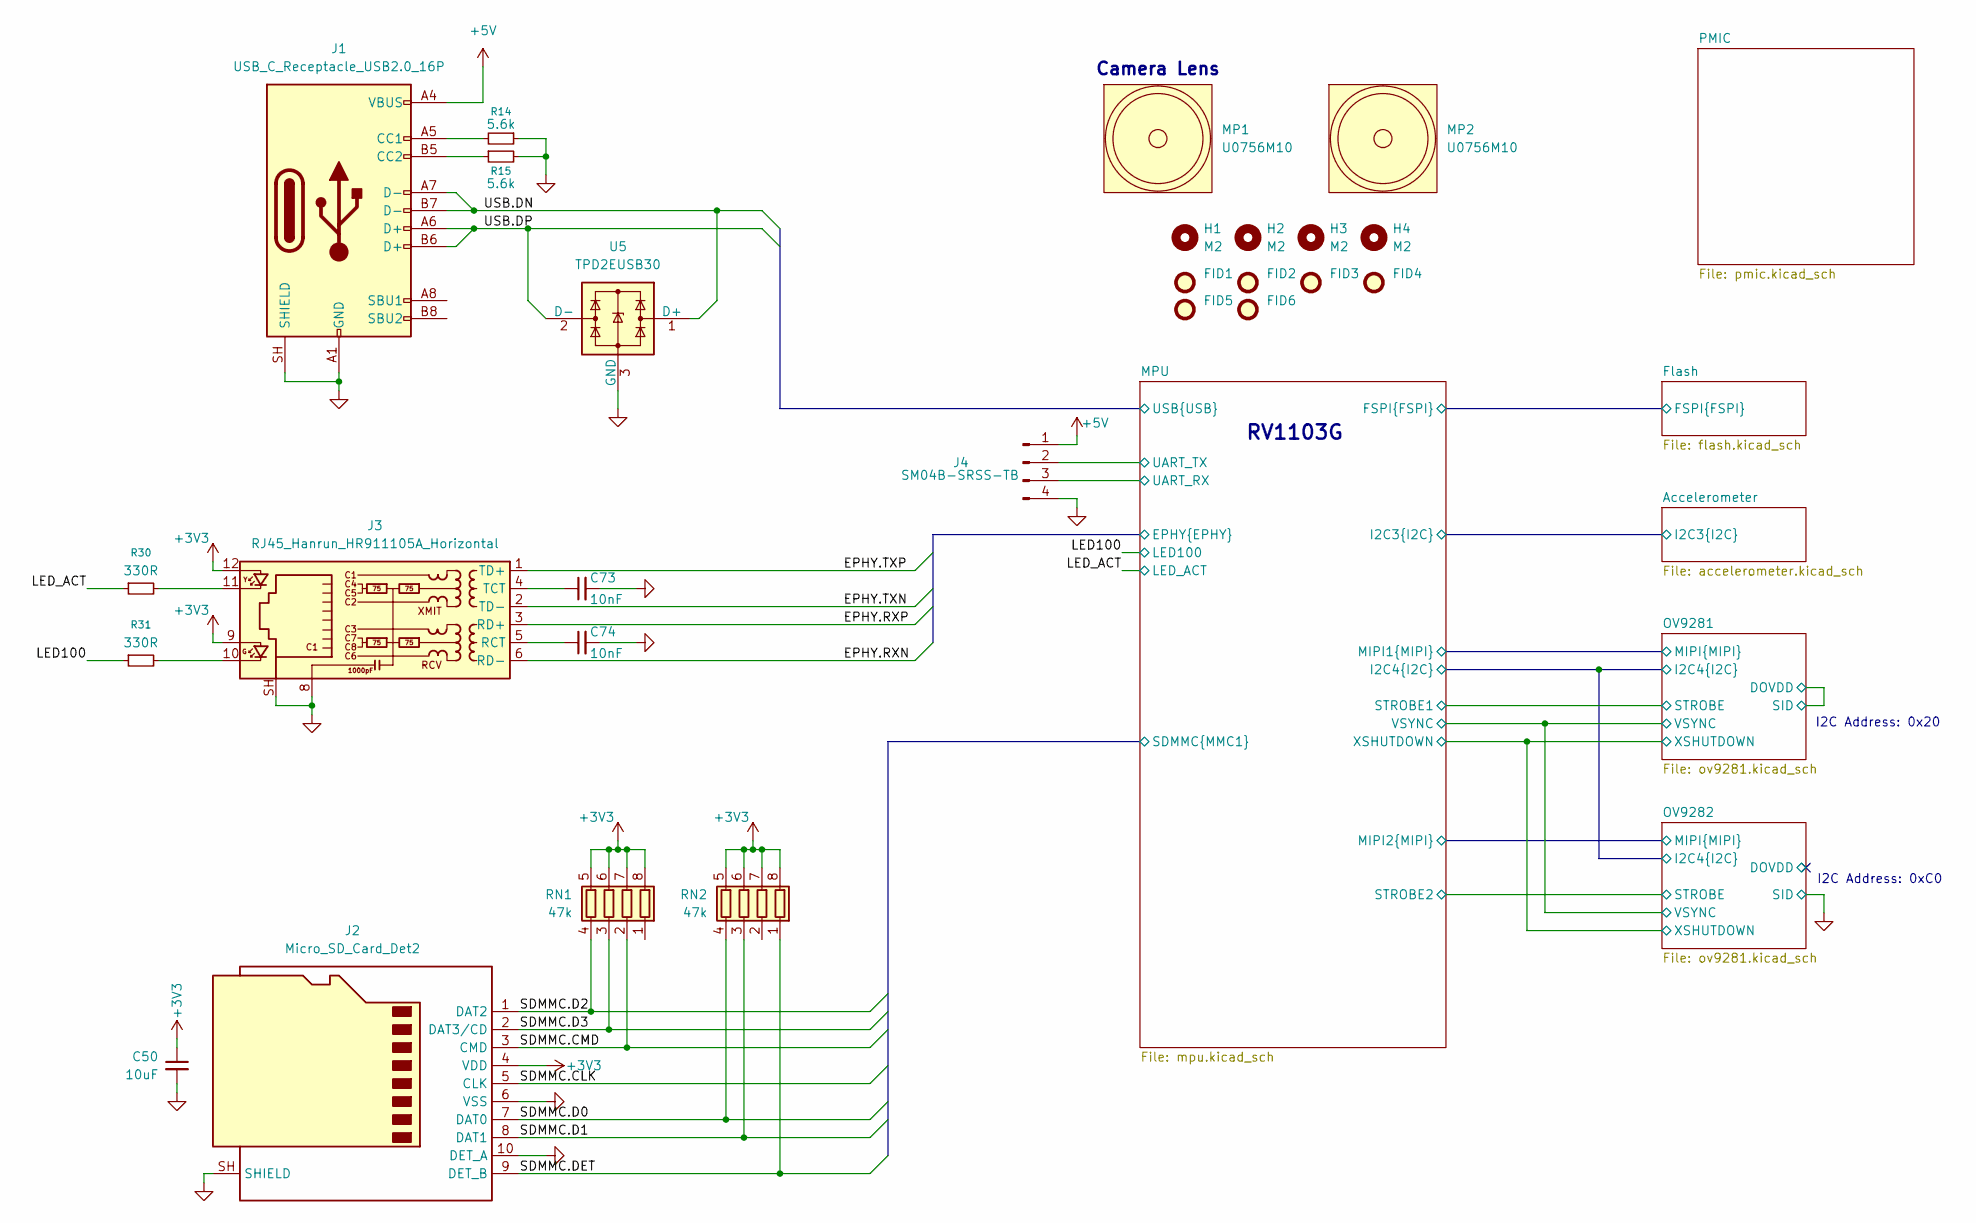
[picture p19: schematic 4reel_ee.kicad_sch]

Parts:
C50: 10uF; C_0402_1005Metric; MPN GRM155R60J106ME05D
C73, C74: 10nF; C_0402_1005Metric; MPN C0402C103K5REC7411
FID1, FID2, FID3, FID4, FID5, FID6: Fiducial; Fiducial_0.5mm_Mask1.5mm
H1, H2, H3, H4: M2; MountingHole_2.2mm_M2
J1: USB_C_Receptacle_USB2.0_16P; USB_C_Receptacle_GCT_USB4105-xx-A_16P_TopMnt_Horizontal; MPN USB4105-GF-A-120
J2: Micro_SD_Card_Det2; microSD_HC_Hirose_DM3AT-SF-PEJM5; MPN DM3AT-SF-PEJM5
J3: RJ45_Hanrun_HR911105A_Horizontal; MPN HR911105A
J4: SM04B-SRSS-TB; JST_SH_SM04B-SRSS-TB_1x04-1MP_P1.00mm_Horizontal; MPN SM04B-SRSS-TB
MP1, MP2: Camera_Lens_20mm; MPN U0756M10
R14, R15: 5.6k; R_0402_1005Metric; MPN RC0402FR-075K6L
R30, R31: 330R; R_0402_1005Metric; MPN RC0402FR-07330RL
RN1, RN2: 47k; R_Array_Concave_4x0402; MPN CAT10-473J4LF
U5: TPD2EUSB30; Texas_DRT-3; MPN TPD2EUSB30ADRTR

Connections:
+3V3: C50.1, J2.4 (VDD), J3.9, J3.12, RN1.5 (R4.2), RN1.6 (R3.2), RN1.7 (R2.2), RN1.8 (R1.2), RN2.5 (R4.2), RN2.6 (R3.2), RN2.7 (R2.2), RN2.8 (R1.2); also elsewhere on the board
+5V: J1.A4 (VBUS), J1.A9 (VBUS), J1.B4 (VBUS), J1.B9 (VBUS), J4.1; also elsewhere on the board
/LED100: R31.1; also elsewhere on the board
/LED_ACT: R30.1; also elsewhere on the board
/MPU/EPHY.RXN: J3.6 (RD-); also elsewhere on the board
/MPU/EPHY.RXP: J3.3 (RD+); also elsewhere on the board
/MPU/EPHY.TXN: J3.2 (TD-); also elsewhere on the board
/MPU/EPHY.TXP: J3.1 (TD+); also elsewhere on the board
/MPU/SDMMC.CLK: J2.5 (CLK); also elsewhere on the board
/MPU/SDMMC.CMD: J2.3 (CMD), RN1.2 (R2.1); also elsewhere on the board
/MPU/SDMMC.D0: J2.7 (DAT0), RN2.4 (R4.1); also elsewhere on the board
/MPU/SDMMC.D1: J2.8 (DAT1), RN2.3 (R3.1); also elsewhere on the board
/MPU/SDMMC.D2: J2.1 (DAT2), RN1.4 (R4.1); also elsewhere on the board
/MPU/SDMMC.D3: J2.2 (DAT3/CD), RN1.3 (R3.1); also elsewhere on the board
/MPU/SDMMC.DET: J2.9 (DET_B), RN2.1 (R1.1); also elsewhere on the board
/MPU/UART_RX: J4.3; also elsewhere on the board
/MPU/UART_TX: J4.2; also elsewhere on the board
/MPU/USB.DN: J1.A7 (D-), J1.B7 (D-), U5.1 (D+); also elsewhere on the board
/MPU/USB.DP: J1.A6 (D+), J1.B6 (D+), U5.2 (D-); also elsewhere on the board
GND: C50.2, C73.2, C74.2, J1.A1 (GND), J1.A12 (GND), J1.B1 (GND), J1.B12 (GND), J1.SH (SHIELD), J2.6 (VSS), J2.10 (DET_A), J2.SH (SHIELD), J3.8, J3.SH, J4.4, R14.1, R15.2, U5.3 (GND); also elsewhere on the board
unnamed: J1.A5 (CC1), R14.2
unnamed: J1.B5 (CC2), R15.1
unnamed: J3.10, R31.2
unnamed: J3.11, R30.2
unnamed: C74.1, J3.5 (RCT)
unnamed: C73.1, J3.4 (TCT)

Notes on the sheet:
Camera Lens
I2C Address: 0x20
I2C Address: 0xC0
RV1103G

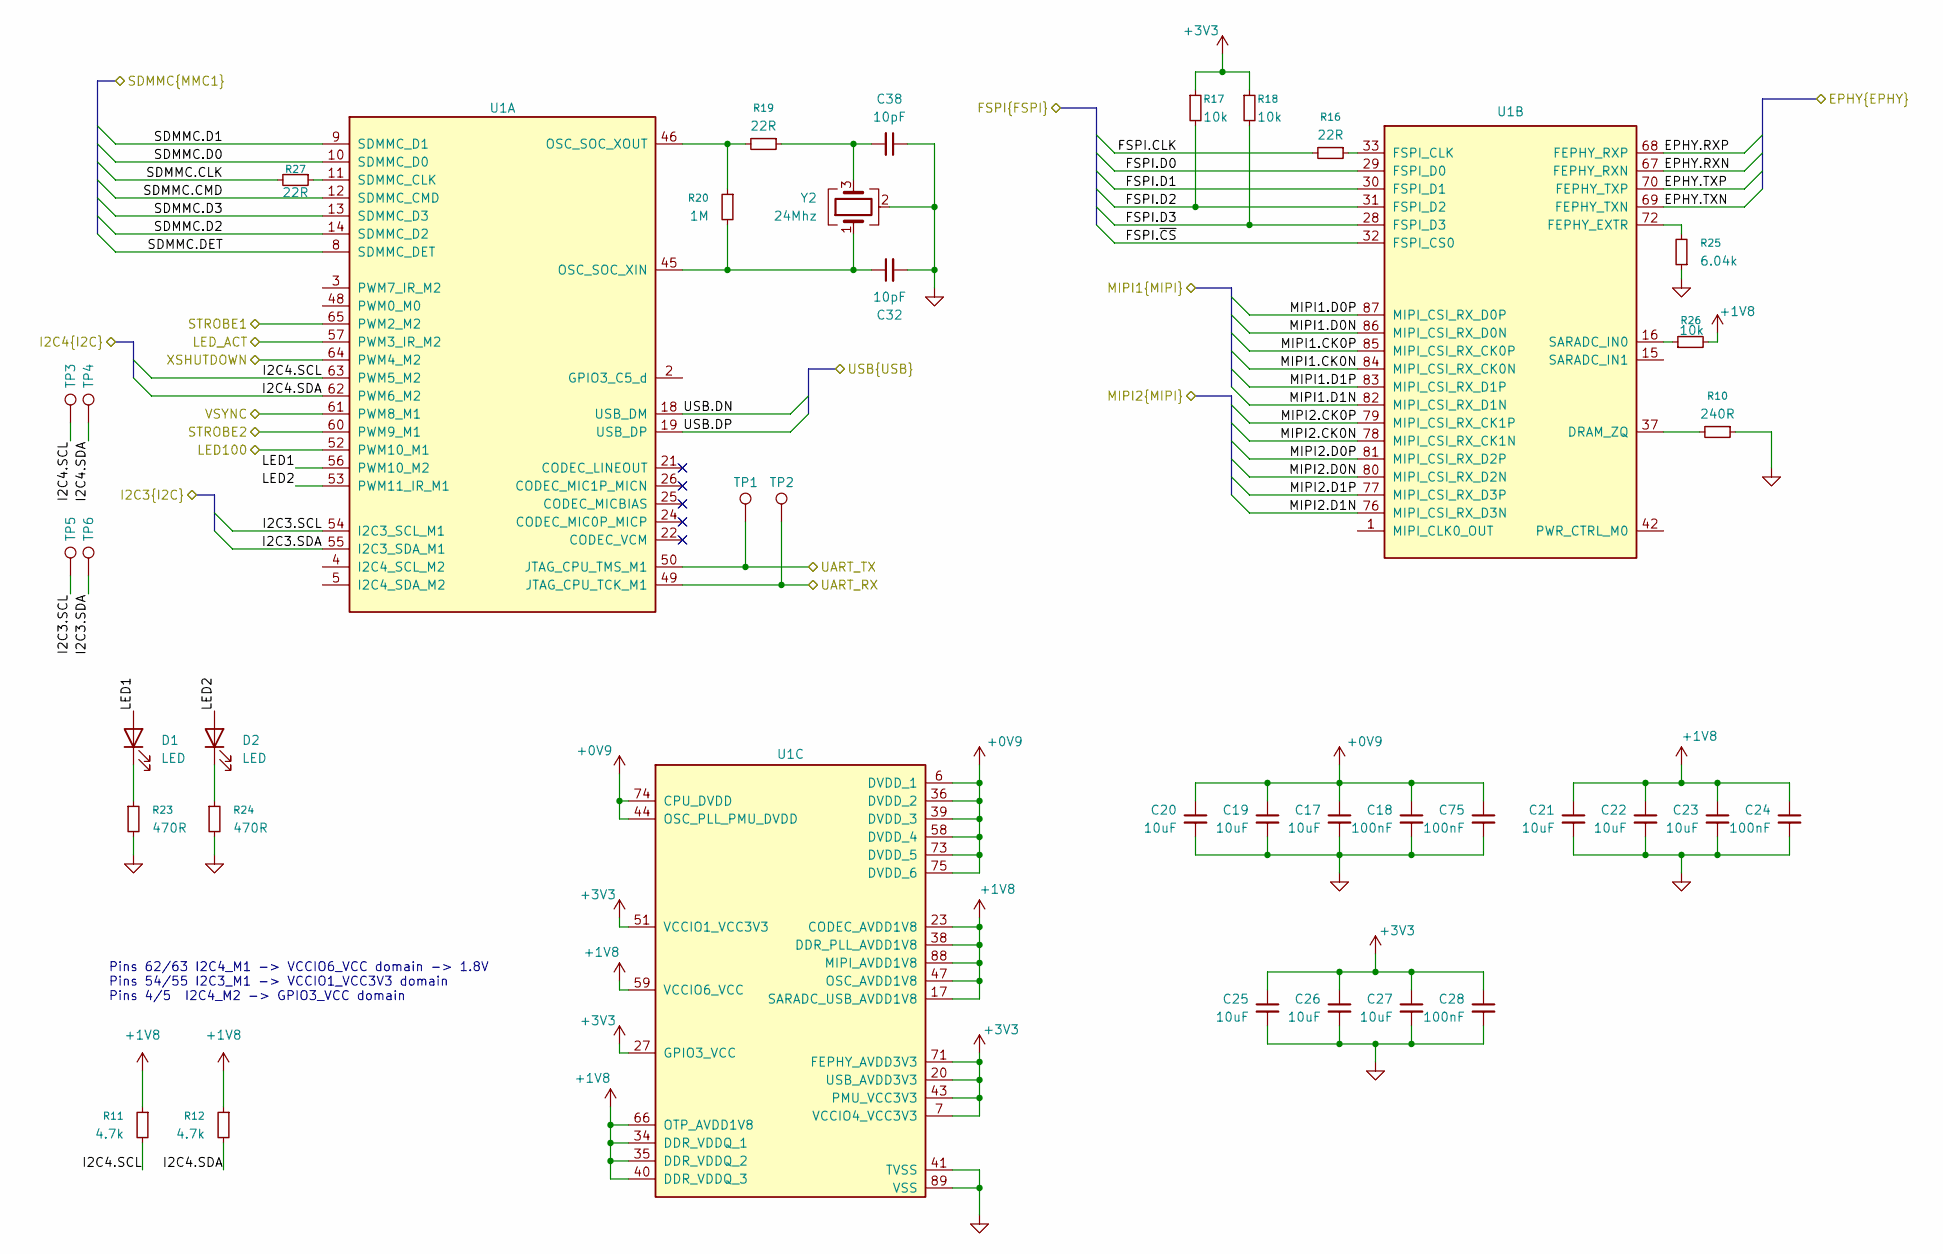
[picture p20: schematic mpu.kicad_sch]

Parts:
C17, C19, C20, C21, C22, C23, C25, C26, C27: 10uF; C_0402_1005Metric; MPN GRM155R60J106ME05D
C18, C24, C28, C75: 100nF; C_0402_1005Metric; MPN CL05B104KP5VPNC
C32, C38: 10pF; C_0402_1005Metric; MPN GCM1555C1H100JA16D
D1, D2: LED; LED_0402_1005Metric; MPN LTST-C281KGKT
R10: 240R; R_0402_1005Metric; MPN RC0402FR-07240RL
R11, R12: 4.7k; R_0402_1005Metric; MPN RC0402FR-074K7L
R16, R19: 22R; R_0402_1005Metric; MPN RC0402FR-0722RL
R17, R18, R26: 10k; R_0402_1005Metric; MPN RC0402FR-0710KL
R20: 1M; R_0402_1005Metric; MPN RC0402FR-071ML
R23, R24: 470R; R_0402_1005Metric; MPN RC0402FR-07470RL
R25: 6.04k; R_0402_1005Metric; MPN RC0402FR-076K04L
R27: 22R; R_0201_0603Metric; MPN RC0201FR-0722RL
TP1, TP2: TestPoint; TestPoint_Pad_1.5x1.5mm
TP3, TP4, TP5, TP6: TestPoint; TestPoint_Pad_1.0x1.0mm
U1: RV1103G; Rockchip_QFN-88-1EP_9x9mm_P0.35mm_EP6.5x6.5mm; MPN RV1103BG3
Y2: 24Mhz; Crystal_SMD_2016-4Pin_2.0x1.6mm; MPN ECS-240-8-37B-CKY-TR

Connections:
+0V9: C17.1, C18.1, C19.1, C20.1, C75.1, U1.6 (DVDD_1), U1.36 (DVDD_2), U1.39 (DVDD_3), U1.44 (OSC_PLL_PMU_DVDD), U1.58 (DVDD_4), U1.73 (DVDD_5), U1.74 (CPU_DVDD), U1.75 (DVDD_6); also elsewhere on the board
+1V8: C21.1, C22.1, C23.1, C24.1, R11.1, R12.1, R26.2, U1.17 (SARADC_USB_AVDD1V8), U1.23 (CODEC_AVDD1V8), U1.34 (DDR_VDDQ_1), U1.35 (DDR_VDDQ_2), U1.38 (DDR_PLL_AVDD1V8), U1.40 (DDR_VDDQ_3), U1.47 (OSC_AVDD1V8), U1.59 (VCCIO6_VCC), U1.66 (OTP_AVDD1V8), U1.88 (MIPI_AVDD1V8); also elsewhere on the board
+3V3: C25.1, C26.1, C27.1, C28.1, R17.1, R18.1, U1.7 (VCCIO4_VCC3V3), U1.20 (USB_AVDD3V3), U1.27 (GPIO3_VCC), U1.43 (PMU_VCC3V3), U1.51 (VCCIO1_VCC3V3), U1.71 (FEPHY_AVDD3V3); also elsewhere on the board
/Accelerometer/I2C3.SCL: TP5.1 (1_1), U1.54 (I2C3_SCL_M1); also elsewhere on the board
/Accelerometer/I2C3.SDA: TP6.1 (1_1), U1.55 (I2C3_SDA_M1); also elsewhere on the board
/Flash/FSPI.CLK: R16.2; also elsewhere on the board
/Flash/FSPI.D0: U1.29 (FSPI_D0); also elsewhere on the board
/Flash/FSPI.D1: U1.30 (FSPI_D1); also elsewhere on the board
/Flash/FSPI.D2: R17.2, U1.31 (FSPI_D2); also elsewhere on the board
/Flash/FSPI.D3: R18.2, U1.28 (FSPI_D3); also elsewhere on the board
/Flash/FSPI.~CS: U1.32 (FSPI_CS0); also elsewhere on the board
/LED100: U1.52 (PWM10_M1); also elsewhere on the board
/LED_ACT: U1.57 (PWM3_IR_M2); also elsewhere on the board
/MPU/EPHY.RXN: U1.67 (FEPHY_RXN); also elsewhere on the board
/MPU/EPHY.RXP: U1.68 (FEPHY_RXP); also elsewhere on the board
/MPU/EPHY.TXN: U1.69 (FEPHY_TXN); also elsewhere on the board
/MPU/EPHY.TXP: U1.70 (FEPHY_TXP); also elsewhere on the board
/MPU/I2C4.SCL: R11.2, TP3.1 (1_1), U1.63 (PWM5_M2); also elsewhere on the board
/MPU/I2C4.SDA: R12.2, TP4.1 (1_1), U1.62 (PWM6_M2); also elsewhere on the board
/MPU/LED1: D1.2 (A), U1.56 (PWM10_M2)
/MPU/LED2: D2.2 (A), U1.53 (PWM11_IR_M1)
/MPU/MIPI1.CK0N: U1.84 (MIPI_CSI_RX_CK0N); also elsewhere on the board
/MPU/MIPI1.CK0P: U1.85 (MIPI_CSI_RX_CK0P); also elsewhere on the board
/MPU/MIPI1.D0N: U1.86 (MIPI_CSI_RX_D0N); also elsewhere on the board
/MPU/MIPI1.D0P: U1.87 (MIPI_CSI_RX_D0P); also elsewhere on the board
/MPU/MIPI1.D1N: U1.82 (MIPI_CSI_RX_D1N); also elsewhere on the board
/MPU/MIPI1.D1P: U1.83 (MIPI_CSI_RX_D1P); also elsewhere on the board
/MPU/MIPI2.CK0N: U1.78 (MIPI_CSI_RX_CK1N); also elsewhere on the board
/MPU/MIPI2.CK0P: U1.79 (MIPI_CSI_RX_CK1P); also elsewhere on the board
/MPU/MIPI2.D0N: U1.80 (MIPI_CSI_RX_D2N); also elsewhere on the board
/MPU/MIPI2.D0P: U1.81 (MIPI_CSI_RX_D2P); also elsewhere on the board
/MPU/MIPI2.D1N: U1.76 (MIPI_CSI_RX_D3N); also elsewhere on the board
/MPU/MIPI2.D1P: U1.77 (MIPI_CSI_RX_D3P); also elsewhere on the board
/MPU/SDMMC.CLK: R27.2; also elsewhere on the board
/MPU/SDMMC.CMD: U1.12 (SDMMC_CMD); also elsewhere on the board
/MPU/SDMMC.D0: U1.10 (SDMMC_D0); also elsewhere on the board
/MPU/SDMMC.D1: U1.9 (SDMMC_D1); also elsewhere on the board
/MPU/SDMMC.D2: U1.14 (SDMMC_D2); also elsewhere on the board
/MPU/SDMMC.D3: U1.13 (SDMMC_D3); also elsewhere on the board
/MPU/SDMMC.DET: U1.8 (SDMMC_DET); also elsewhere on the board
/MPU/STROBE1: U1.65 (PWM2_M2); also elsewhere on the board
/MPU/STROBE2: U1.60 (PWM9_M1); also elsewhere on the board
/MPU/UART_RX: TP2.1 (1_1), U1.49 (JTAG_CPU_TCK_M1); also elsewhere on the board
/MPU/UART_TX: TP1.1 (1_1), U1.50 (JTAG_CPU_TMS_M1); also elsewhere on the board
/MPU/USB.DN: U1.18 (USB_DM); also elsewhere on the board
/MPU/USB.DP: U1.19 (USB_DP); also elsewhere on the board
/MPU/VSYNC: U1.61 (PWM8_M1); also elsewhere on the board
/MPU/XSHUTDOWN: U1.64 (PWM4_M2); also elsewhere on the board
GND: C17.2, C18.2, C19.2, C20.2, C21.2, C22.2, C23.2, C24.2, C25.2, C26.2, C27.2, C28.2, C32.2, C38.1, C75.2, R10.1, R23.2, R24.2, R25.1, U1.41 (TVSS), U1.89 (VSS), Y2.2 (G), Y2.4 (G); also elsewhere on the board
unnamed: C38.2, R19.1, Y2.3
unnamed: D1.1 (K), R23.1
unnamed: D2.1 (K), R24.1
unnamed: R10.2, U1.37 (DRAM_ZQ)
unnamed: R25.2, U1.72 (FEPHY_EXTR)
unnamed: R16.1, U1.33 (FSPI_CLK)
unnamed: R26.1, U1.16 (SARADC_IN0)
unnamed: C32.1, R20.2, U1.45 (OSC_SOC_XIN), Y2.1
unnamed: R19.2, R20.1, U1.46 (OSC_SOC_XOUT)
unnamed: R27.1, U1.11 (SDMMC_CLK)

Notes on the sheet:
Pins 62/63 I2C4_M1 -> VCCIO6_VCC domain -> 1.8V Pins 54/55 I2C3_M1 -> VCCIO1_VCC3V3 domain Pins 4/5 I2C4_M2 -> GPIO3_VCC domain

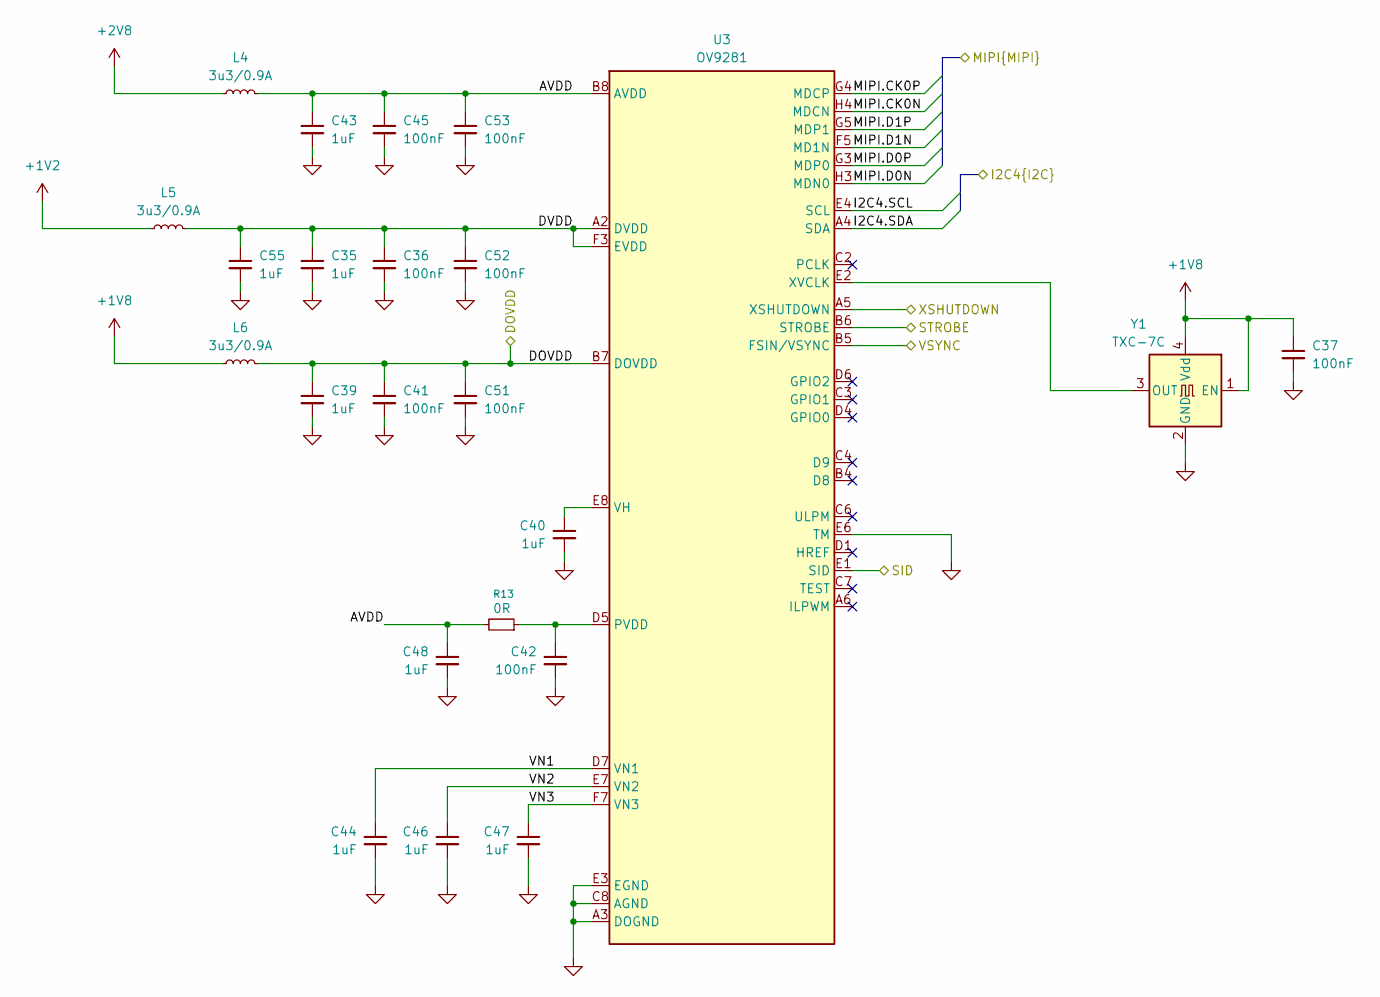
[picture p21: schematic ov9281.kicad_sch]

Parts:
C35, C39, C40, C43, C44, C46, C47, C48, C55: 1uF; C_0402_1005Metric; MPN C0402C105K9PACTU
C36, C37, C41, C42, C45, C51, C52, C53: 100nF; C_0402_1005Metric; MPN CL05B104KP5VPNC
L4, L5, L6: 3u3/0.9A; L_0805_2012Metric; MPN MLP2012S3R3MT0S1
R13: 0R; R_0402_1005Metric; MPN RC0402FR-070RL
U3: ImageSensor_OV9281; OV9281; MPN OV9281
Y1: TXC-7C; Oscillator_SMD_TXC_7C-4Pin_5.0x3.2mm; MPN SX5M24.000D20F30TNN

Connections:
+1V2: L5.1; also elsewhere on the board
+1V8: C37.1, L6.1, Y1.1 (EN), Y1.4 (Vdd); also elsewhere on the board
+2V8: L4.1; also elsewhere on the board
/MPU/I2C4.SCL: U3.E4 (SCL); also elsewhere on the board
/MPU/I2C4.SDA: U3.A4 (SDA); also elsewhere on the board
/MPU/MIPI1.CK0N: U3.H4 (MDCN); also elsewhere on the board
/MPU/MIPI1.CK0P: U3.G4 (MDCP); also elsewhere on the board
/MPU/MIPI1.D0N: U3.H3 (MDN0); also elsewhere on the board
/MPU/MIPI1.D0P: U3.G3 (MDP0); also elsewhere on the board
/MPU/MIPI1.D1N: U3.F5 (MD1N); also elsewhere on the board
/MPU/MIPI1.D1P: U3.G5 (MDP1); also elsewhere on the board
/MPU/STROBE1: U3.B6 (STROBE); also elsewhere on the board
/MPU/VSYNC: U3.B5 (FSIN/VSYNC); also elsewhere on the board
/MPU/XSHUTDOWN: U3.A5 (XSHUTDOWN); also elsewhere on the board
/OV9281/AVDD: C43.1, C45.1, C48.1, C53.1, L4.2, R13.2, U3.B8 (AVDD), U3.C1 (AVDD), U3.G7 (AVDD), U3.G8 (AVDD)
/OV9281/DOVDD: C39.1, C41.1, C51.1, L6.2, U3.B7 (DOVDD), U3.D3 (DOVDD), U3.E1 (SID), U3.H2 (DOVDD), U3.H6 (DOVDD)
/OV9281/DVDD: C35.1, C36.1, C52.1, C55.1, L5.2, U3.A2 (DVDD), U3.B1 (DVDD), U3.B3 (DVDD), U3.C5 (DVDD), U3.D8 (DVDD), U3.F2 (DVDD), U3.F3 (EVDD), U3.G1 (DVDD), U3.G6 (DVDD), U3.H5 (EVDD)
/OV9281/VN1: C44.1, U3.D7 (VN1)
/OV9281/VN2: C46.1, U3.E7 (VN2)
/OV9281/VN3: C47.1, U3.F7 (VN3)
GND: C35.2, C36.2, C37.2, C39.2, C40.2, C41.2, C42.2, C43.2, C44.2, C45.2, C46.2, C47.2, C48.2, C51.2, C52.2, C53.2, C55.2, U3.A3 (DOGND), U3.A7 (DOGND), U3.B2 (DOGND), U3.C8 (AGND), U3.D2 (AGND), U3.E3 (EGND), U3.E5 (EGND), U3.E6 (TM), U3.F1 (DOGND), U3.F4 (DOGND), U3.F6 (DOGND), U3.F8 (AGND), U3.G2 (DOGND), U3.H7 (AGND), Y1.2 (GND); also elsewhere on the board
unnamed: C42.1, R13.1, U3.D5 (PVDD)
unnamed: C40.1, U3.E8 (VH)
unnamed: U3.E2 (XVCLK), Y1.3 (OUT)

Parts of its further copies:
C56, C57, C58, C59, C60, C64, C65, C69, C71: 1uF; C_0402_1005Metric; MPN C0402C105K9PACTU
C61, C62, C63, C66, C67, C68, C70, C72: 100nF; C_0402_1005Metric; MPN CL05B104KP5VPNC
L7, L8, L9: 3u3/0.9A; L_0805_2012Metric; MPN MLP2012S3R3MT0S1
R32: 0R; R_0402_1005Metric; MPN RC0402FR-070RL
U9: ImageSensor_OV9281; OV9281; MPN OV9281
Y3: TXC-7C; Oscillator_SMD_TXC_7C-4Pin_5.0x3.2mm; MPN SX5M24.000D20F30TNN

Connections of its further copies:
+1V2: L7.1; also elsewhere on the board
+1V8: C72.1, L9.1, Y3.1 (EN), Y3.4 (Vdd); also elsewhere on the board
+2V8: L8.1; also elsewhere on the board
/MPU/I2C4.SCL: U9.E4 (SCL); also elsewhere on the board
/MPU/I2C4.SDA: U9.A4 (SDA); also elsewhere on the board
/MPU/MIPI2.CK0N: U9.H4 (MDCN); also elsewhere on the board
/MPU/MIPI2.CK0P: U9.G4 (MDCP); also elsewhere on the board
/MPU/MIPI2.D0N: U9.H3 (MDN0); also elsewhere on the board
/MPU/MIPI2.D0P: U9.G3 (MDP0); also elsewhere on the board
/MPU/MIPI2.D1N: U9.F5 (MD1N); also elsewhere on the board
/MPU/MIPI2.D1P: U9.G5 (MDP1); also elsewhere on the board
/MPU/STROBE2: U9.B6 (STROBE); also elsewhere on the board
/MPU/VSYNC: U9.B5 (FSIN/VSYNC); also elsewhere on the board
/MPU/XSHUTDOWN: U9.A5 (XSHUTDOWN); also elsewhere on the board
/OV9282/AVDD: C57.1, C61.1, C64.1, C66.1, L8.2, R32.2, U9.B8 (AVDD), U9.C1 (AVDD), U9.G7 (AVDD), U9.G8 (AVDD)
/OV9282/DOVDD: C59.1, C63.1, C68.1, L9.2, U9.B7 (DOVDD), U9.D3 (DOVDD), U9.H2 (DOVDD), U9.H6 (DOVDD)
/OV9282/DVDD: C56.1, C58.1, C62.1, C67.1, L7.2, U9.A2 (DVDD), U9.B1 (DVDD), U9.B3 (DVDD), U9.C5 (DVDD), U9.D8 (DVDD), U9.F2 (DVDD), U9.F3 (EVDD), U9.G1 (DVDD), U9.G6 (DVDD), U9.H5 (EVDD)
/OV9282/VN1: C60.1, U9.D7 (VN1)
/OV9282/VN2: C65.1, U9.E7 (VN2)
/OV9282/VN3: C69.1, U9.F7 (VN3)
GND: C56.2, C57.2, C58.2, C59.2, C60.2, C61.2, C62.2, C63.2, C64.2, C65.2, C66.2, C67.2, C68.2, C69.2, C70.2, C71.2, C72.2, U9.A3 (DOGND), U9.A7 (DOGND), U9.B2 (DOGND), U9.C8 (AGND), U9.D2 (AGND), U9.E1 (SID), U9.E3 (EGND), U9.E5 (EGND), U9.E6 (TM), U9.F1 (DOGND), U9.F4 (DOGND), U9.F6 (DOGND), U9.F8 (AGND), U9.G2 (DOGND), U9.H7 (AGND), Y3.2 (GND); also elsewhere on the board
unnamed: C70.1, R32.1, U9.D5 (PVDD)
unnamed: C71.1, U9.E8 (VH)
unnamed: U9.E2 (XVCLK), Y3.3 (OUT)

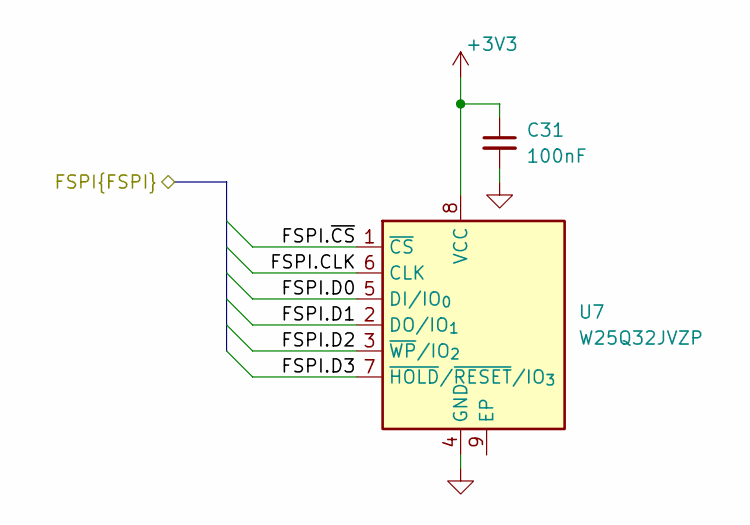
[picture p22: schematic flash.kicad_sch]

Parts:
C31: 100nF; C_0402_1005Metric; MPN CL05B104KP5VPNC
U7: W25Q32JVZP; WSON-8-1EP_6x5mm_P1.27mm_EP3.4x4.3mm; MPN W25Q32JVZPIQ

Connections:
+3V3: C31.1, U7.8 (VCC); also elsewhere on the board
/Flash/FSPI.CLK: U7.6 (CLK); also elsewhere on the board
/Flash/FSPI.D0: U7.5 (DI/IO_{0}); also elsewhere on the board
/Flash/FSPI.D1: U7.2 (DO/IO_{1}); also elsewhere on the board
/Flash/FSPI.D2: U7.3 (~WP/IO_{2}); also elsewhere on the board
/Flash/FSPI.D3: U7.7 (~HOLD/~RESET/IO_{3}); also elsewhere on the board
/Flash/FSPI.~CS: U7.1 (~CS); also elsewhere on the board
GND: C31.2, U7.4 (GND); also elsewhere on the board

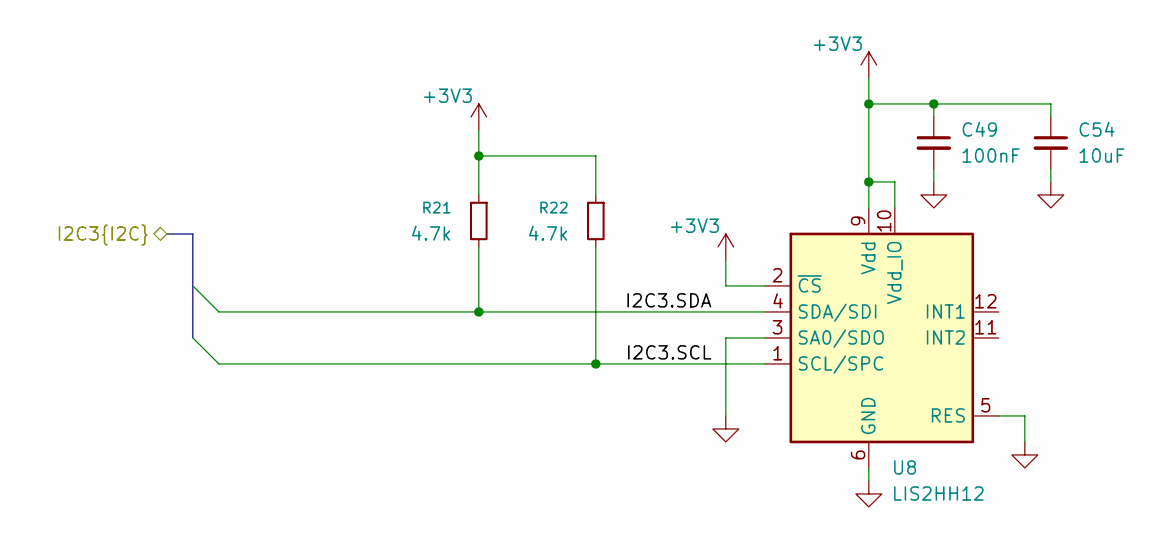
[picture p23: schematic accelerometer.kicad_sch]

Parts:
C49: 100nF; C_0402_1005Metric; MPN CL05B104KP5VPNC
C54: 10uF; C_0402_1005Metric; MPN GRM155R60J106ME05D
R21, R22: 4.7k; R_0402_1005Metric; MPN RC0402FR-074K7L
U8: LIS2HH12; LGA-12_2x2mm_P0.5mm; MPN LIS2HH12TR

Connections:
+3V3: C49.1, C54.1, R21.1, R22.1, U8.2 (~CS), U8.9 (Vdd), U8.10 (Vdd_IO); also elsewhere on the board
/Accelerometer/I2C3.SCL: R22.2, U8.1 (SCL/SPC); also elsewhere on the board
/Accelerometer/I2C3.SDA: R21.2, U8.4 (SDA/SDI); also elsewhere on the board
GND: C49.2, C54.2, U8.3 (SA0/SDO), U8.5 (RES), U8.6 (GND), U8.7 (GND), U8.8 (GND); also elsewhere on the board

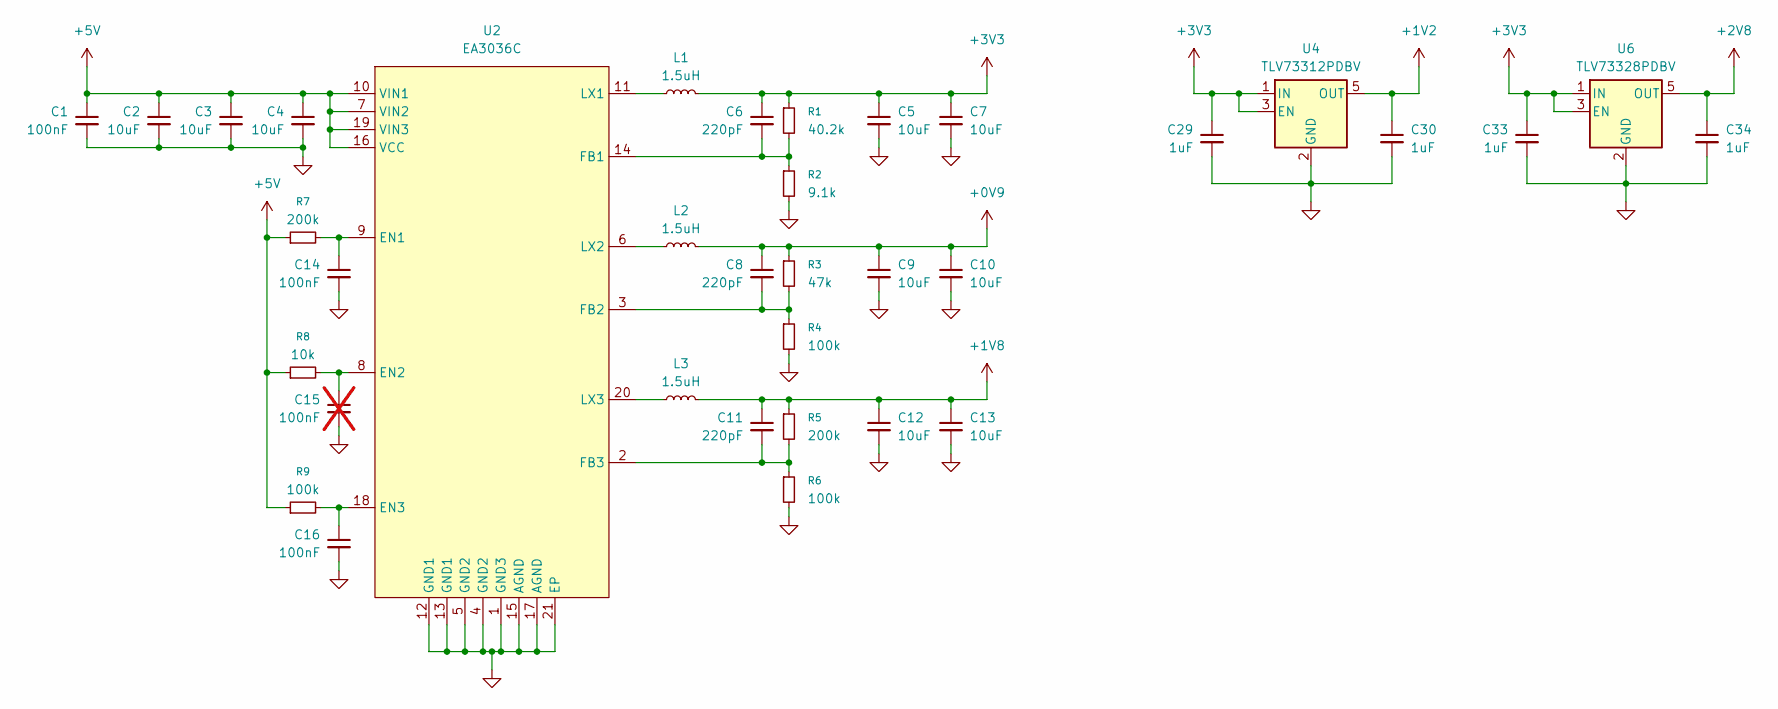
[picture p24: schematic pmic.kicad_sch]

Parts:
C1, C14, C16: 100nF; C_0402_1005Metric; MPN CL05B104KP5VPNC
C2, C3, C4, C5, C7, C9, C10, C12, C13: 10uF; C_0402_1005Metric; MPN GRM155R60J106ME05D
C6, C8, C11: 220pF; C_0402_1005Metric; MPN GCM1555C1H221JA16D
C15: 100nF; C_0402_1005Metric; MPN CL05B104KP5VPNC; not fitted
C29, C30, C33, C34: 1uF; C_0402_1005Metric; MPN C0402C105K9PACTU
L1, L2, L3: 1.5uH; L_1008_2520Metric; MPN DFE252012P-1R5M=P2
R1: 40.2k; R_0402_1005Metric; MPN RC0402FR-0740K2L
R2: 9.1k; R_0402_1005Metric; MPN RC0402FR-079K1L
R3: 47k; R_0402_1005Metric; MPN RC0402FR-0747KL
R4, R6, R9: 100k; R_0402_1005Metric; MPN RC0402FR-07100KL
R5, R7: 200k; R_0402_1005Metric; MPN RC0402FR-07200KL
R8: 10k; R_0402_1005Metric; MPN RC0402FR-0710KL
U2: EA3036C; QFN-20-1EP_3x3mm_P0.4mm_EP1.65x1.65mm; MPN EA3036CQBR
U4: TLV73312PDBV; SOT-23-5; MPN TLV73312PDBV
U6: TLV73328PDBV; SOT-23-5; MPN TLV73328PDBVR

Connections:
+0V9: C8.1, C9.1, C10.1, L2.2, R3.1; also elsewhere on the board
+1V2: C30.1, U4.5 (OUT); also elsewhere on the board
+1V8: C11.1, C12.1, C13.1, L3.2, R5.1; also elsewhere on the board
+2V8: C34.1, U6.5 (OUT); also elsewhere on the board
+3V3: C5.1, C6.1, C7.1, C29.1, C33.1, L1.2, R1.1, U4.1 (IN), U4.3 (EN), U6.1 (IN), U6.3 (EN); also elsewhere on the board
+5V: C1.1, C2.1, C3.1, C4.1, R7.1, R8.1, R9.1, U2.7 (VIN2), U2.10 (VIN1), U2.16 (VCC), U2.19 (VIN3); also elsewhere on the board
GND: C1.2, C2.2, C3.2, C4.2, C5.2, C7.2, C9.2, C10.2, C12.2, C13.2, C14.2, C15.2, C16.2, C29.2, C30.2, C33.2, C34.2, R2.2, R4.2, R6.2, U2.1 (GND3), U2.4 (GND2), U2.5 (GND2), U2.12 (GND1), U2.13 (GND1), U2.15 (AGND), U2.17 (AGND), U2.21 (EP), U4.2 (GND), U6.2 (GND); also elsewhere on the board
unnamed: C14.1, R7.2, U2.9 (EN1)
unnamed: C15.1, R8.2, U2.8 (EN2)
unnamed: C16.1, R9.2, U2.18 (EN3)
unnamed: C6.2, R1.2, R2.1, U2.14 (FB1)
unnamed: C8.2, R3.2, R4.1, U2.3 (FB2)
unnamed: C11.2, R5.2, R6.1, U2.2 (FB3)
unnamed: L1.1, U2.11 (LX1)
unnamed: L2.1, U2.6 (LX2)
unnamed: L3.1, U2.20 (LX3)

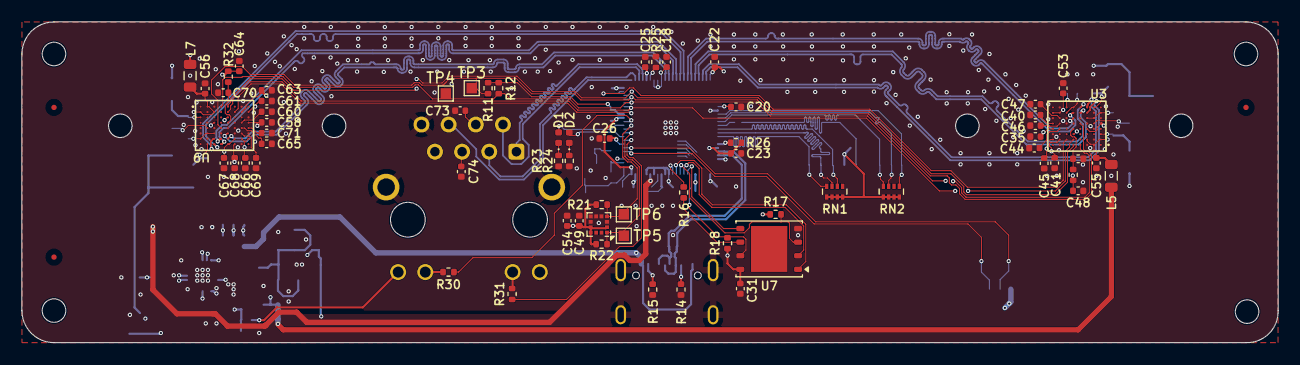
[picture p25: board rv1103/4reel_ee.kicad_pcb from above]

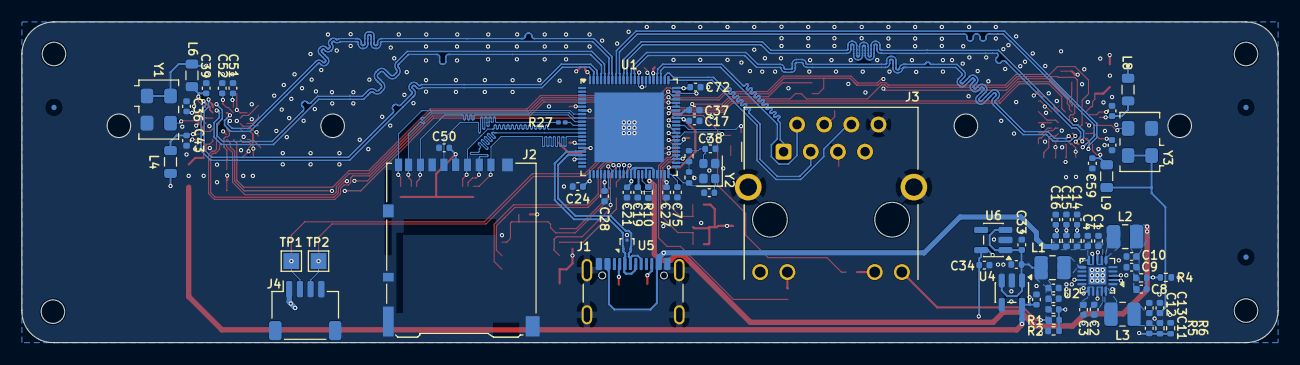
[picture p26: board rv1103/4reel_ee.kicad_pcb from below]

Board: 4 copper layers, 117.5 x 30.0 mm, 152 parts (77 on the bottom side), 95 nets.

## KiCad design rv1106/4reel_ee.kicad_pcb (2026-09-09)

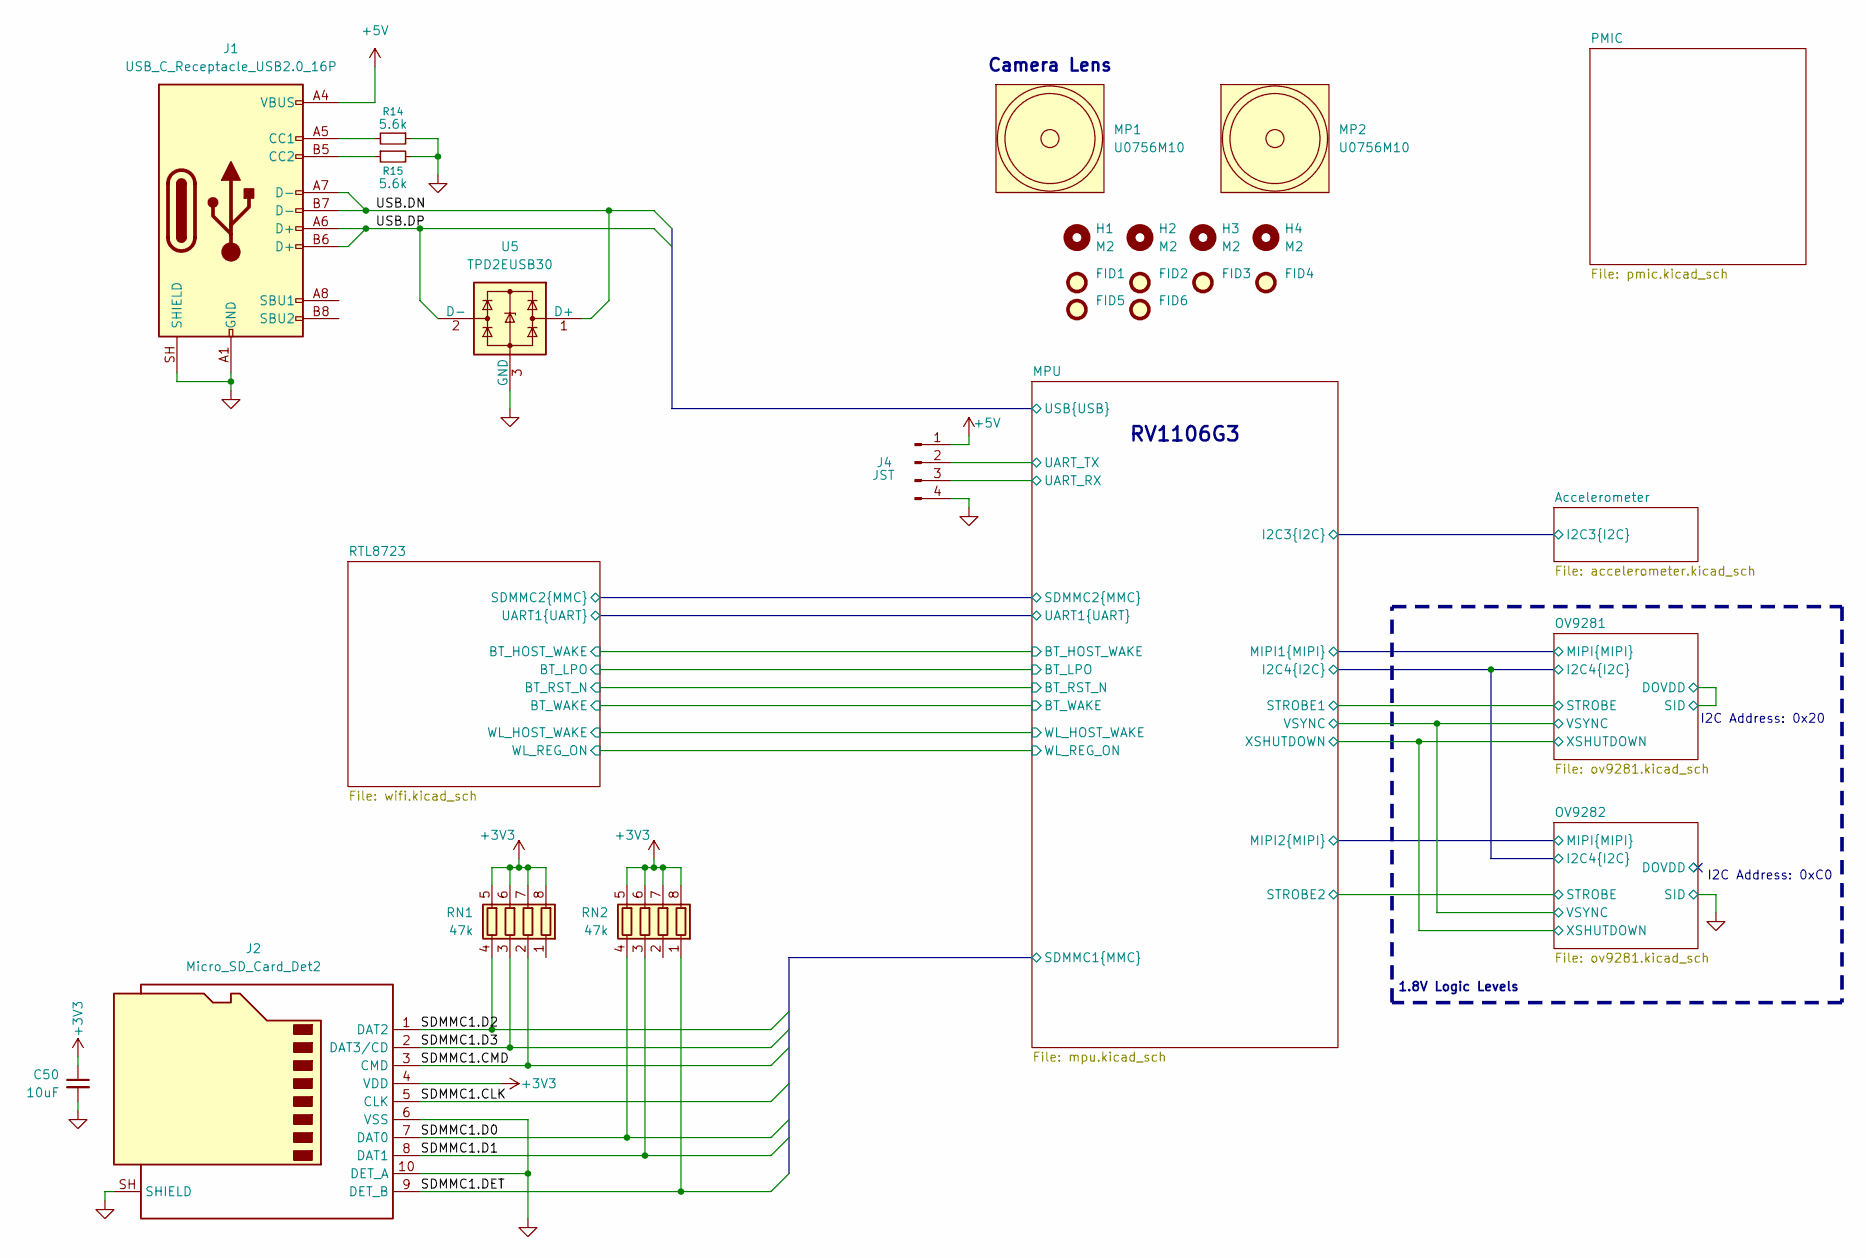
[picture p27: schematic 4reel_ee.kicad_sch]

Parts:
C50: 10uF; C_0402_1005Metric; MPN GRM155R60J106ME05D
FID1, FID2, FID3, FID4, FID5, FID6: Fiducial; Fiducial_0.5mm_Mask1.5mm
H1, H2, H3, H4: M2; MountingHole_2.2mm_M2
J1: USB_C_Receptacle_USB2.0_16P; USB_C_Receptacle_GCT_USB4105-xx-A_16P_TopMnt_Horizontal; MPN USB4105-GF-A-120
J2: Micro_SD_Card_Det2; microSD_HC_Hirose_DM3AT-SF-PEJM5; MPN DM3AT-SF-PEJM5
J4: JST; JST_SH_SM04B-SRSS-TB_1x04-1MP_P1.00mm_Horizontal; MPN SM04B-SRSS-TB
MP1, MP2: Camera_Lens_20mm; MPN U0756M10
R14, R15: 5.6k; R_0402_1005Metric; MPN RC0402FR-075K6L
RN1, RN2: 47k; R_Array_Concave_4x0402; MPN CAT10-473J4LF
U5: TPD2EUSB30; Texas_DRT-3; MPN TPD2EUSB30ADRTR

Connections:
+3V3: C50.1, J2.4 (VDD), RN1.5 (R4.2), RN1.6 (R3.2), RN1.7 (R2.2), RN1.8 (R1.2), RN2.5 (R4.2), RN2.6 (R3.2), RN2.7 (R2.2), RN2.8 (R1.2); also elsewhere on the board
+5V: J1.A4 (VBUS), J1.A9 (VBUS), J1.B4 (VBUS), J1.B9 (VBUS), J4.1; also elsewhere on the board
/MPU/SDMMC1.CLK: J2.5 (CLK); also elsewhere on the board
/MPU/SDMMC1.CMD: J2.3 (CMD), RN1.2 (R2.1); also elsewhere on the board
/MPU/SDMMC1.D0: J2.7 (DAT0), RN2.4 (R4.1); also elsewhere on the board
/MPU/SDMMC1.D1: J2.8 (DAT1), RN2.3 (R3.1); also elsewhere on the board
/MPU/SDMMC1.D2: J2.1 (DAT2), RN1.4 (R4.1); also elsewhere on the board
/MPU/SDMMC1.D3: J2.2 (DAT3/CD), RN1.3 (R3.1); also elsewhere on the board
/MPU/SDMMC1.DET: J2.9 (DET_B), RN2.1 (R1.1); also elsewhere on the board
/MPU/UART_RX: J4.3; also elsewhere on the board
/MPU/UART_TX: J4.2; also elsewhere on the board
/MPU/USB.DN: J1.A7 (D-), J1.B7 (D-), U5.1 (D+); also elsewhere on the board
/MPU/USB.DP: J1.A6 (D+), J1.B6 (D+), U5.2 (D-); also elsewhere on the board
GND: C50.2, J1.A1 (GND), J1.A12 (GND), J1.B1 (GND), J1.B12 (GND), J1.SH (SHIELD), J2.6 (VSS), J2.10 (DET_A), J2.SH (SHIELD), J4.4, R14.1, R15.2, U5.3 (GND); also elsewhere on the board
unnamed: J1.A5 (CC1), R14.2
unnamed: J1.B5 (CC2), R15.1

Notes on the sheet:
Camera Lens
I2C Address: 0x20
I2C Address: 0xC0
1.8V Logic Levels
RV1106G3

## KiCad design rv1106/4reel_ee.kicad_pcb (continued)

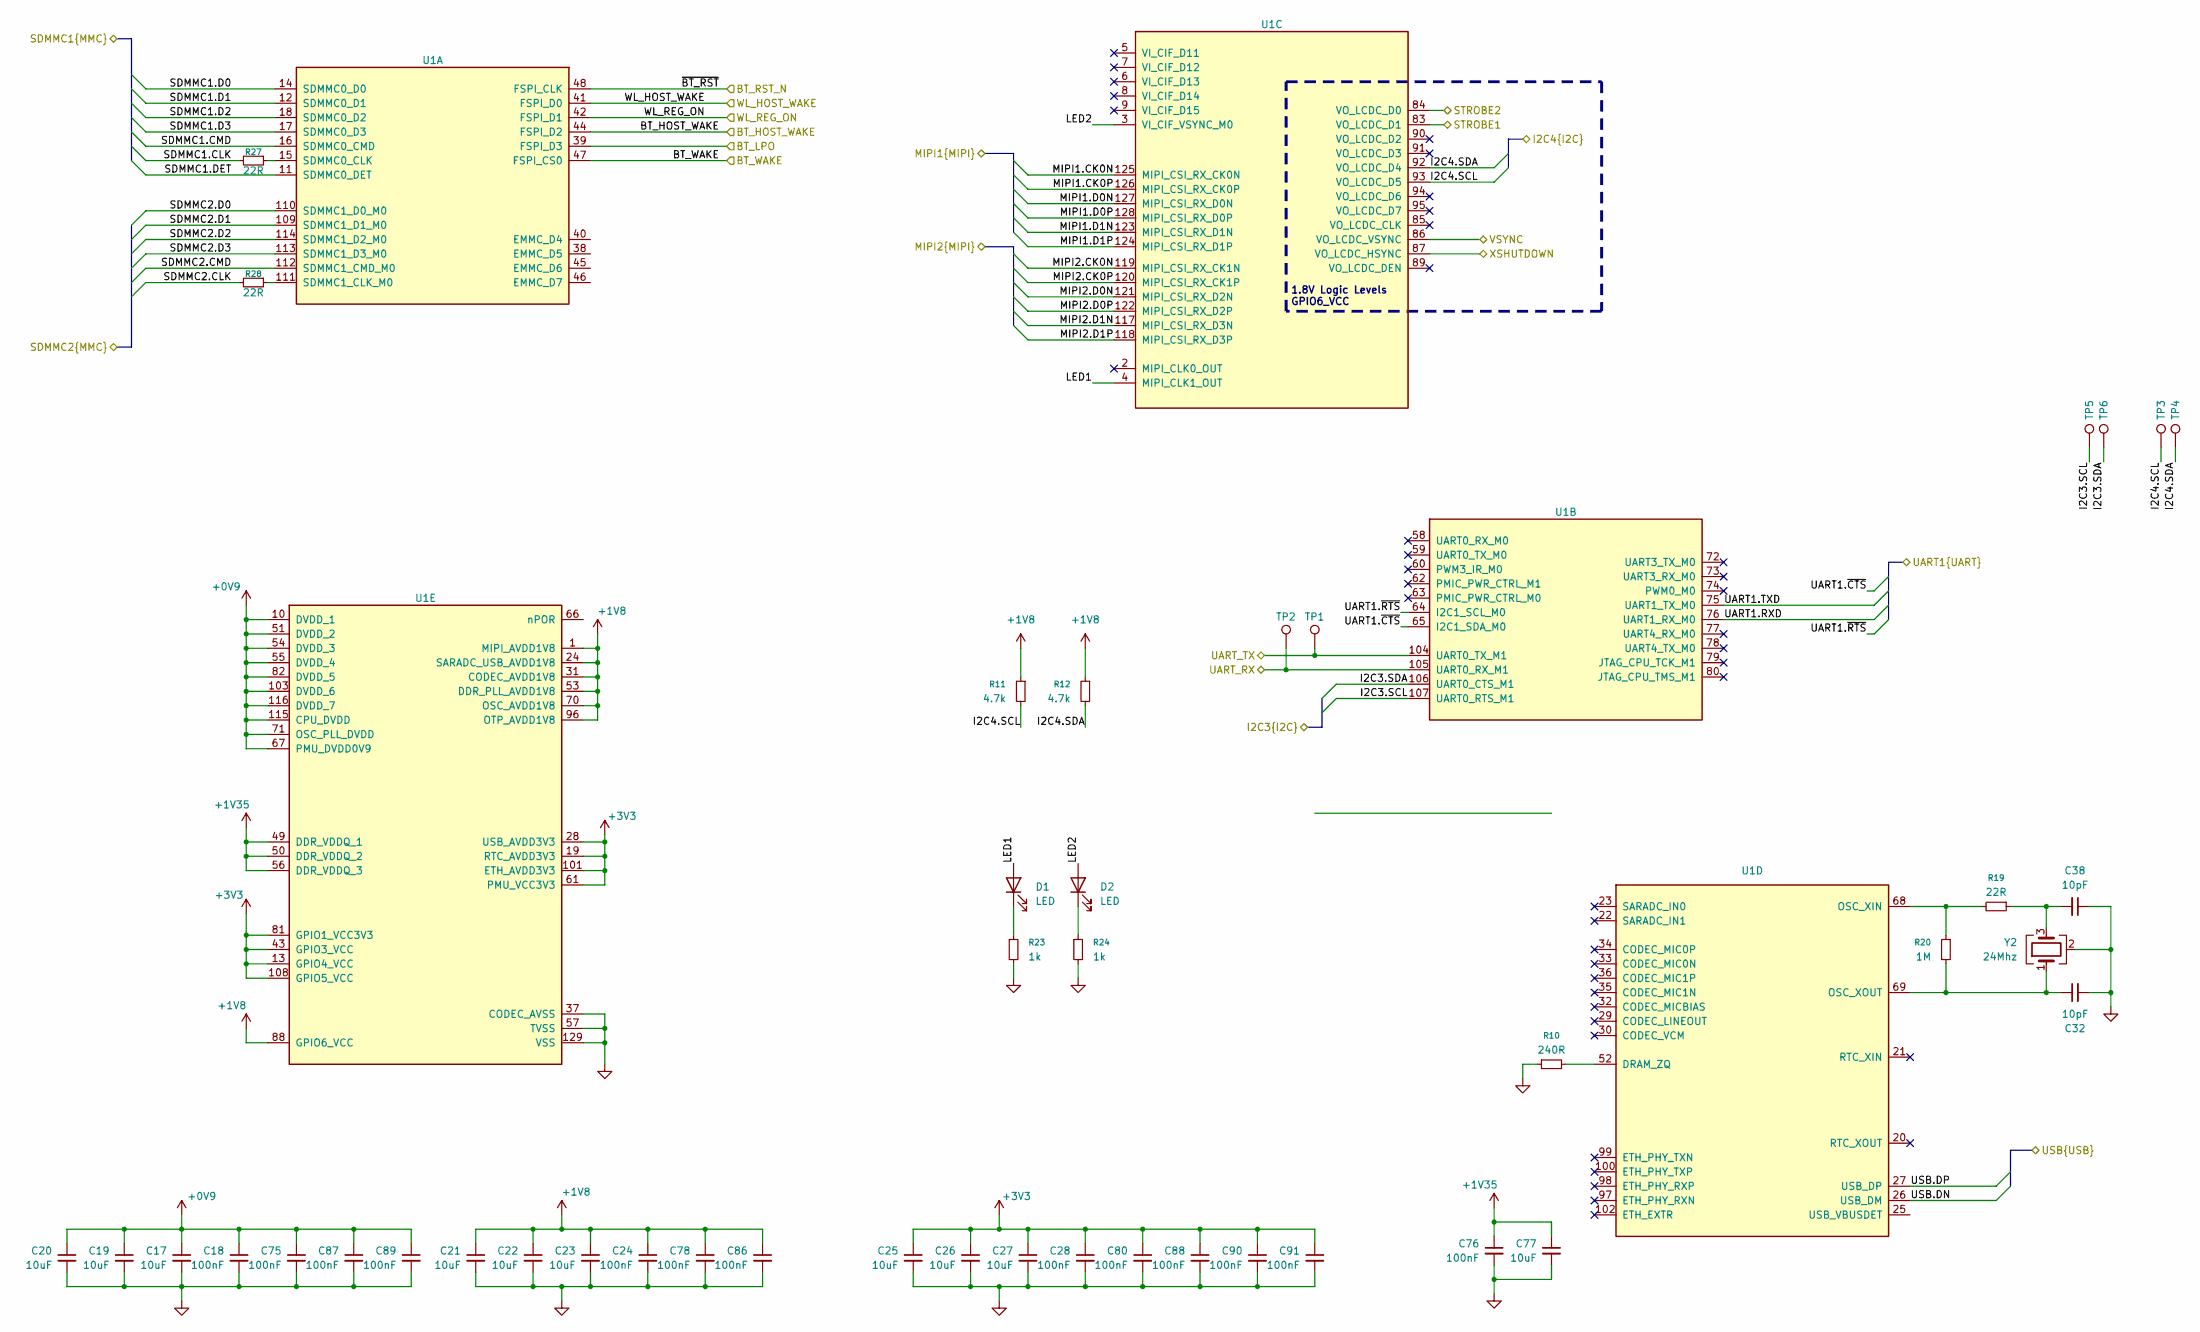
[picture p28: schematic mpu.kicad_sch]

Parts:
C17, C19, C20, C21, C22, C23, C25, C26, C27: 10uF; C_0402_1005Metric; MPN GRM155R60J106ME05D
C18, C24, C28, C75, C76, C78, C80, C86, C87, C88, C89, C90, C91: 100nF; C_0201_0603Metric
C32, C38: 10pF; C_0402_1005Metric; MPN GCM1555C1H100JA16D
C77: 10uF; C_0402_1005Metric
D1, D2: LED; LED_0402_1005Metric; MPN LTST-C281KGKT
R10: 240R; R_0201_0603Metric
R11, R12: 4.7k; R_0402_1005Metric; MPN RC0402FR-074K7L
R19: 22R; R_0402_1005Metric; MPN RC0402FR-0722RL
R20: 1M; R_0402_1005Metric; MPN RC0402FR-071ML
R23, R24: 1k; R_0402_1005Metric; MPN RC0402FR-071KL
R27, R28: 22R; R_0201_0603Metric; MPN RC0201FR-0722RL
TP1, TP2: TestPoint; TestPoint_Pad_1.5x1.5mm
TP3, TP4, TP5, TP6: TestPoint; TestPoint_Pad_1.0x1.0mm
U1: RV1106G3; Rockchip_QFN-128-1EP_12.3x12.3mm_P0.35mm_EP7x7mm; MPN RV1106G3
Y2: 24Mhz; Crystal_SMD_2016-4Pin_2.0x1.6mm; MPN ECS-240-8-37B-CKY-TR

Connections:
+0V9: C17.1, C18.1, C19.1, C20.1, C75.1, C87.1, C89.1, U1.10 (DVDD_1), U1.51 (DVDD_2), U1.54 (DVDD_3), U1.55 (DVDD_4), U1.67 (PMU_DVDD0V9), U1.71 (OSC_PLL_DVDD), U1.82 (DVDD_5), U1.103 (DVDD_6), U1.115 (CPU_DVDD), U1.116 (DVDD_7); also elsewhere on the board
+1V8: C21.1, C22.1, C23.1, C24.1, C78.1, C86.1, R11.1, R12.1, U1.1 (MIPI_AVDD1V8), U1.24 (SARADC_USB_AVDD1V8), U1.31 (CODEC_AVDD1V8), U1.53 (DDR_PLL_AVDD1V8), U1.70 (OSC_AVDD1V8), U1.88 (GPIO6_VCC), U1.96 (OTP_AVDD1V8); also elsewhere on the board
+1V35: C76.1, C77.1, U1.49 (DDR_VDDQ_1), U1.50 (DDR_VDDQ_2), U1.56 (DDR_VDDQ_3); also elsewhere on the board
+3V3: C25.1, C26.1, C27.1, C28.1, C80.1, C88.1, C90.1, C91.1, U1.13 (GPIO4_VCC), U1.19 (RTC_AVDD3V3), U1.28 (USB_AVDD3V3), U1.43 (GPIO3_VCC), U1.61 (PMU_VCC3V3), U1.81 (GPIO1_VCC3V3), U1.101 (ETH_AVDD3V3), U1.108 (GPIO5_VCC); also elsewhere on the board
/Accelerometer/I2C3.SCL: TP5.1 (1_1), U1.107 (UART0_RTS_M1); also elsewhere on the board
/Accelerometer/I2C3.SDA: TP6.1 (1_1), U1.106 (UART0_CTS_M1); also elsewhere on the board
/MPU/BT_HOST_WAKE: U1.44 (FSPI_D2); also elsewhere on the board
/MPU/BT_LPO: U1.39 (FSPI_D3); also elsewhere on the board
/MPU/BT_WAKE: U1.47 (FSPI_CS0); also elsewhere on the board
/MPU/I2C4.SCL: R11.2, TP3.1 (1_1), U1.93 (VO_LCDC_D5); also elsewhere on the board
/MPU/I2C4.SDA: R12.2, TP4.1 (1_1), U1.92 (VO_LCDC_D4); also elsewhere on the board
/MPU/LED1: D1.2 (A), U1.4 (MIPI_CLK1_OUT)
/MPU/LED2: D2.2 (A), U1.3 (VI_CIF_VSYNC_M0)
/MPU/MIPI1.CK0N: U1.125 (MIPI_CSI_RX_CK0N); also elsewhere on the board
/MPU/MIPI1.CK0P: U1.126 (MIPI_CSI_RX_CK0P); also elsewhere on the board
/MPU/MIPI1.D0N: U1.127 (MIPI_CSI_RX_D0N); also elsewhere on the board
/MPU/MIPI1.D0P: U1.128 (MIPI_CSI_RX_D0P); also elsewhere on the board
/MPU/MIPI1.D1N: U1.123 (MIPI_CSI_RX_D1N); also elsewhere on the board
/MPU/MIPI1.D1P: U1.124 (MIPI_CSI_RX_D1P); also elsewhere on the board
/MPU/MIPI2.CK0N: U1.119 (MIPI_CSI_RX_CK1N); also elsewhere on the board
/MPU/MIPI2.CK0P: U1.120 (MIPI_CSI_RX_CK1P); also elsewhere on the board
/MPU/MIPI2.D0N: U1.121 (MIPI_CSI_RX_D2N); also elsewhere on the board
/MPU/MIPI2.D0P: U1.122 (MIPI_CSI_RX_D2P); also elsewhere on the board
/MPU/MIPI2.D1N: U1.117 (MIPI_CSI_RX_D3N); also elsewhere on the board
/MPU/MIPI2.D1P: U1.118 (MIPI_CSI_RX_D3P); also elsewhere on the board
/MPU/SDMMC1.CLK: R27.2; also elsewhere on the board
/MPU/SDMMC1.CMD: U1.16 (SDMMC0_CMD); also elsewhere on the board
/MPU/SDMMC1.D0: U1.14 (SDMMC0_D0); also elsewhere on the board
/MPU/SDMMC1.D1: U1.12 (SDMMC0_D1); also elsewhere on the board
/MPU/SDMMC1.D2: U1.18 (SDMMC0_D2); also elsewhere on the board
/MPU/SDMMC1.D3: U1.17 (SDMMC0_D3); also elsewhere on the board
/MPU/SDMMC1.DET: U1.11 (SDMMC0_DET); also elsewhere on the board
/MPU/SDMMC2.CLK: R28.2; also elsewhere on the board
/MPU/SDMMC2.CMD: U1.112 (SDMMC1_CMD_M0); also elsewhere on the board
/MPU/SDMMC2.D0: U1.110 (SDMMC1_D0_M0); also elsewhere on the board
/MPU/SDMMC2.D1: U1.109 (SDMMC1_D1_M0); also elsewhere on the board
/MPU/SDMMC2.D2: U1.114 (SDMMC1_D2_M0); also elsewhere on the board
/MPU/SDMMC2.D3: U1.113 (SDMMC1_D3_M0); also elsewhere on the board
/MPU/STROBE1: U1.83 (VO_LCDC_D1); also elsewhere on the board
/MPU/STROBE2: U1.84 (VO_LCDC_D0); also elsewhere on the board
/MPU/UART1.RXD: U1.76 (UART1_RX_M0); also elsewhere on the board
/MPU/UART1.TXD: U1.75 (UART1_TX_M0); also elsewhere on the board
/MPU/UART1.~CTS: U1.65 (I2C1_SDA_M0); also elsewhere on the board
/MPU/UART1.~RTS: U1.64 (I2C1_SCL_M0); also elsewhere on the board
/MPU/UART_RX: TP2.1 (1_1), U1.105 (UART0_RX_M1); also elsewhere on the board
/MPU/UART_TX: TP1.1 (1_1), U1.104 (UART0_TX_M1); also elsewhere on the board
/MPU/USB.DN: U1.26 (USB_DM); also elsewhere on the board
/MPU/USB.DP: U1.27 (USB_DP); also elsewhere on the board
/MPU/VSYNC: U1.86 (VO_LCDC_VSYNC); also elsewhere on the board
/MPU/WL_HOST_WAKE: U1.41 (FSPI_D0); also elsewhere on the board
/MPU/WL_REG_ON: U1.42 (FSPI_D1); also elsewhere on the board
/MPU/XSHUTDOWN: U1.87 (VO_LCDC_HSYNC); also elsewhere on the board
/MPU/~BT_RST: U1.48 (FSPI_CLK); also elsewhere on the board
GND: C17.2, C18.2, C19.2, C20.2, C21.2, C22.2, C23.2, C24.2, C25.2, C26.2, C27.2, C28.2, C32.2, C38.1, C75.2, C76.2, C77.2, C78.2, C80.2, C86.2, C87.2, C88.2, C89.2, C90.2, C91.2, R10.1, R23.2, R24.2, U1.37 (CODEC_AVSS), U1.57 (TVSS), U1.129 (VSS), Y2.2 (G), Y2.4 (G); also elsewhere on the board
unnamed: C38.2, R19.1, Y2.3
unnamed: D1.1 (K), R23.1
unnamed: D2.1 (K), R24.1
unnamed: R10.2, U1.52 (DRAM_ZQ)
unnamed: R19.2, R20.1, U1.68 (OSC_XIN)
unnamed: C32.1, R20.2, U1.69 (OSC_XOUT), Y2.1
unnamed: R27.1, U1.15 (SDMMC0_CLK)
unnamed: R28.1, U1.111 (SDMMC1_CLK_M0)

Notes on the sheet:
1.8V Logic Levels GPIO6_VCC

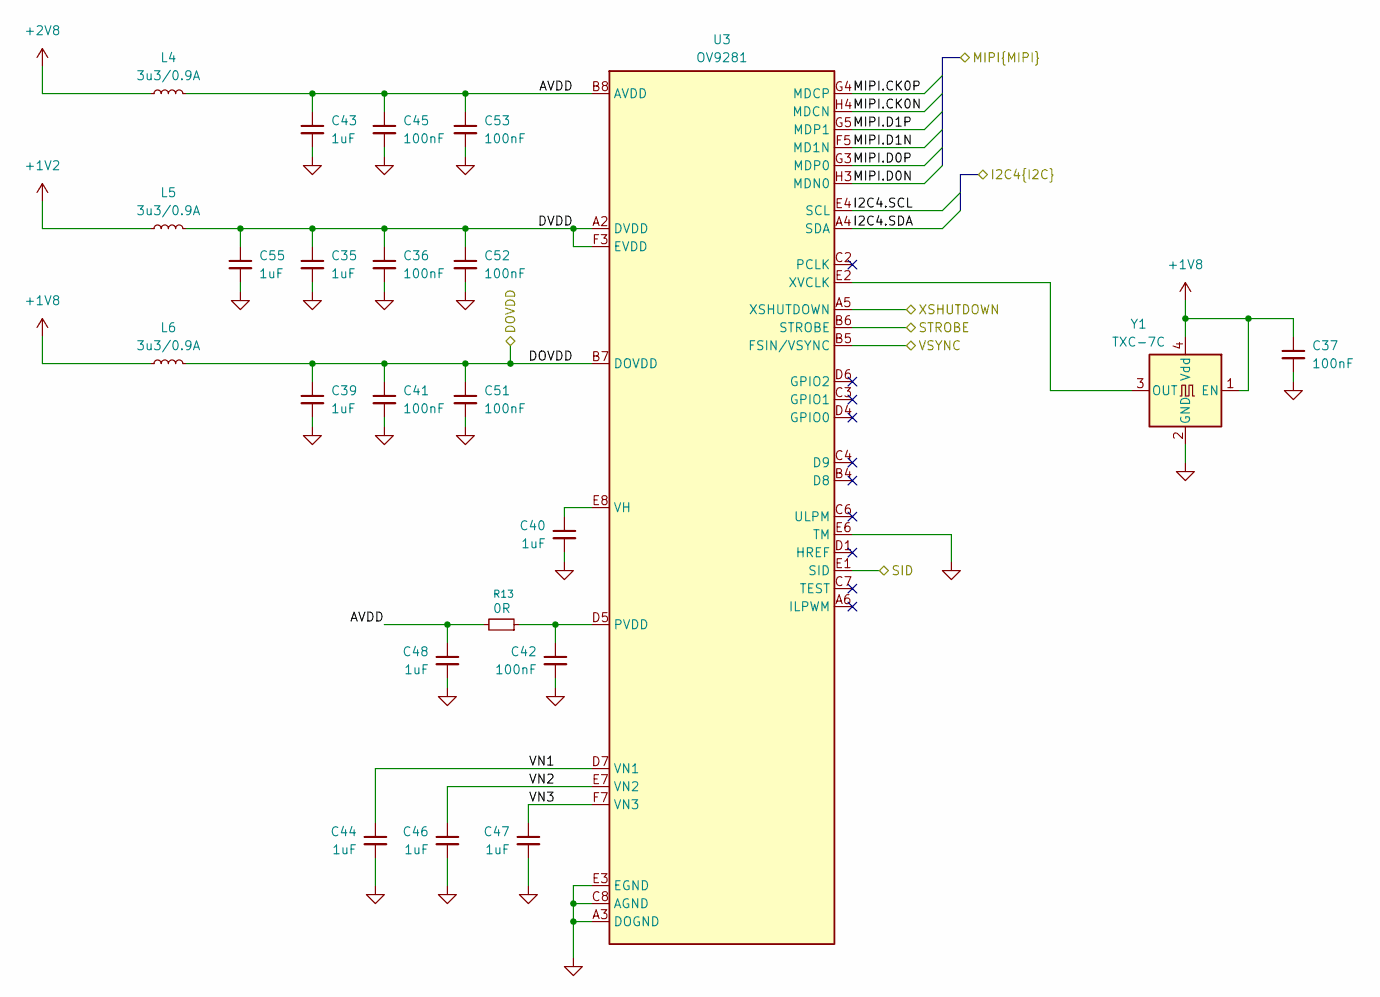
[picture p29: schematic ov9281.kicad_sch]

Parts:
C35, C39, C40, C43, C44, C46, C47, C48, C55: 1uF; C_0402_1005Metric; MPN C0402C105K9PACTU
C36, C37, C41, C42, C45, C51, C52, C53: 100nF; C_0402_1005Metric; MPN CL05B104KP5VPNC
L4, L5, L6: 3u3/0.9A; L_0805_2012Metric; MPN MLP2012S3R3MT0S1
R13: 0R; R_0402_1005Metric; MPN RC0402FR-070RL
U3: ImageSensor_OV9281; OV9281; MPN OV9281
Y1: TXC-7C; Oscillator_SMD_TXC_7C-4Pin_5.0x3.2mm; MPN SX5M24.000D20F30TNN

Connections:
+1V2: L5.1; also elsewhere on the board
+1V8: C37.1, L6.1, Y1.1 (EN), Y1.4 (Vdd); also elsewhere on the board
+2V8: L4.1; also elsewhere on the board
/MPU/I2C4.SCL: U3.E4 (SCL); also elsewhere on the board
/MPU/I2C4.SDA: U3.A4 (SDA); also elsewhere on the board
/MPU/MIPI1.CK0N: U3.H4 (MDCN); also elsewhere on the board
/MPU/MIPI1.CK0P: U3.G4 (MDCP); also elsewhere on the board
/MPU/MIPI1.D0N: U3.H3 (MDN0); also elsewhere on the board
/MPU/MIPI1.D0P: U3.G3 (MDP0); also elsewhere on the board
/MPU/MIPI1.D1N: U3.F5 (MD1N); also elsewhere on the board
/MPU/MIPI1.D1P: U3.G5 (MDP1); also elsewhere on the board
/MPU/STROBE1: U3.B6 (STROBE); also elsewhere on the board
/MPU/VSYNC: U3.B5 (FSIN/VSYNC); also elsewhere on the board
/MPU/XSHUTDOWN: U3.A5 (XSHUTDOWN); also elsewhere on the board
/OV9281/AVDD: C43.1, C45.1, C48.1, C53.1, L4.2, R13.2, U3.B8 (AVDD), U3.C1 (AVDD), U3.G7 (AVDD), U3.G8 (AVDD)
/OV9281/DOVDD: C39.1, C41.1, C51.1, L6.2, U3.B7 (DOVDD), U3.D3 (DOVDD), U3.E1 (SID), U3.H2 (DOVDD), U3.H6 (DOVDD)
/OV9281/DVDD: C35.1, C36.1, C52.1, C55.1, L5.2, U3.A2 (DVDD), U3.B1 (DVDD), U3.B3 (DVDD), U3.C5 (DVDD), U3.D8 (DVDD), U3.F2 (DVDD), U3.F3 (EVDD), U3.G1 (DVDD), U3.G6 (DVDD), U3.H5 (EVDD)
/OV9281/VN1: C44.1, U3.D7 (VN1)
/OV9281/VN2: C46.1, U3.E7 (VN2)
/OV9281/VN3: C47.1, U3.F7 (VN3)
GND: C35.2, C36.2, C37.2, C39.2, C40.2, C41.2, C42.2, C43.2, C44.2, C45.2, C46.2, C47.2, C48.2, C51.2, C52.2, C53.2, C55.2, U3.A3 (DOGND), U3.A7 (DOGND), U3.B2 (DOGND), U3.C8 (AGND), U3.D2 (AGND), U3.E3 (EGND), U3.E5 (EGND), U3.E6 (TM), U3.F1 (DOGND), U3.F4 (DOGND), U3.F6 (DOGND), U3.F8 (AGND), U3.G2 (DOGND), U3.H7 (AGND), Y1.2 (GND); also elsewhere on the board
unnamed: C42.1, R13.1, U3.D5 (PVDD)
unnamed: C40.1, U3.E8 (VH)
unnamed: U3.E2 (XVCLK), Y1.3 (OUT)

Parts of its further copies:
C56, C57, C58, C59, C60, C64, C65, C69, C71: 1uF; C_0402_1005Metric; MPN C0402C105K9PACTU
C61, C62, C63, C66, C67, C68, C70, C72: 100nF; C_0402_1005Metric; MPN CL05B104KP5VPNC
L7, L8, L9: 3u3/0.9A; L_0805_2012Metric; MPN MLP2012S3R3MT0S1
R32: 0R; R_0402_1005Metric; MPN RC0402FR-070RL
U9: ImageSensor_OV9281; OV9281; MPN OV9281
Y3: TXC-7C; Oscillator_SMD_TXC_7C-4Pin_5.0x3.2mm; MPN SX5M24.000D20F30TNN

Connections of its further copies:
+1V2: L7.1; also elsewhere on the board
+1V8: C72.1, L9.1, Y3.1 (EN), Y3.4 (Vdd); also elsewhere on the board
+2V8: L8.1; also elsewhere on the board
/MPU/I2C4.SCL: U9.E4 (SCL); also elsewhere on the board
/MPU/I2C4.SDA: U9.A4 (SDA); also elsewhere on the board
/MPU/MIPI2.CK0N: U9.H4 (MDCN); also elsewhere on the board
/MPU/MIPI2.CK0P: U9.G4 (MDCP); also elsewhere on the board
/MPU/MIPI2.D0N: U9.H3 (MDN0); also elsewhere on the board
/MPU/MIPI2.D0P: U9.G3 (MDP0); also elsewhere on the board
/MPU/MIPI2.D1N: U9.F5 (MD1N); also elsewhere on the board
/MPU/MIPI2.D1P: U9.G5 (MDP1); also elsewhere on the board
/MPU/STROBE2: U9.B6 (STROBE); also elsewhere on the board
/MPU/VSYNC: U9.B5 (FSIN/VSYNC); also elsewhere on the board
/MPU/XSHUTDOWN: U9.A5 (XSHUTDOWN); also elsewhere on the board
/OV9282/AVDD: C57.1, C61.1, C64.1, C66.1, L8.2, R32.2, U9.B8 (AVDD), U9.C1 (AVDD), U9.G7 (AVDD), U9.G8 (AVDD)
/OV9282/DOVDD: C59.1, C63.1, C68.1, L9.2, U9.B7 (DOVDD), U9.D3 (DOVDD), U9.H2 (DOVDD), U9.H6 (DOVDD)
/OV9282/DVDD: C56.1, C58.1, C62.1, C67.1, L7.2, U9.A2 (DVDD), U9.B1 (DVDD), U9.B3 (DVDD), U9.C5 (DVDD), U9.D8 (DVDD), U9.F2 (DVDD), U9.F3 (EVDD), U9.G1 (DVDD), U9.G6 (DVDD), U9.H5 (EVDD)
/OV9282/VN1: C60.1, U9.D7 (VN1)
/OV9282/VN2: C65.1, U9.E7 (VN2)
/OV9282/VN3: C69.1, U9.F7 (VN3)
GND: C56.2, C57.2, C58.2, C59.2, C60.2, C61.2, C62.2, C63.2, C64.2, C65.2, C66.2, C67.2, C68.2, C69.2, C70.2, C71.2, C72.2, U9.A3 (DOGND), U9.A7 (DOGND), U9.B2 (DOGND), U9.C8 (AGND), U9.D2 (AGND), U9.E1 (SID), U9.E3 (EGND), U9.E5 (EGND), U9.E6 (TM), U9.F1 (DOGND), U9.F4 (DOGND), U9.F6 (DOGND), U9.F8 (AGND), U9.G2 (DOGND), U9.H7 (AGND), Y3.2 (GND); also elsewhere on the board
unnamed: C70.1, R32.1, U9.D5 (PVDD)
unnamed: C71.1, U9.E8 (VH)
unnamed: U9.E2 (XVCLK), Y3.3 (OUT)


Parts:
C49: 100nF; C_0402_1005Metric; MPN CL05B104KP5VPNC
C54: 10uF; C_0402_1005Metric; MPN GRM155R60J106ME05D
R21, R22: 4.7k; R_0402_1005Metric; MPN RC0402FR-074K7L
U8: LIS2HH12; LGA-12_2x2mm_P0.5mm; MPN LIS2HH12TR

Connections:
+3V3: C49.1, C54.1, R21.1, R22.1, U8.2 (~CS), U8.9 (Vdd), U8.10 (Vdd_IO); also elsewhere on the board
/Accelerometer/I2C3.SCL: R22.2, U8.1 (SCL/SPC); also elsewhere on the board
/Accelerometer/I2C3.SDA: R21.2, U8.4 (SDA/SDI); also elsewhere on the board
GND: C49.2, C54.2, U8.3 (SA0/SDO), U8.5 (RES), U8.6 (GND), U8.7 (GND), U8.8 (GND); also elsewhere on the board

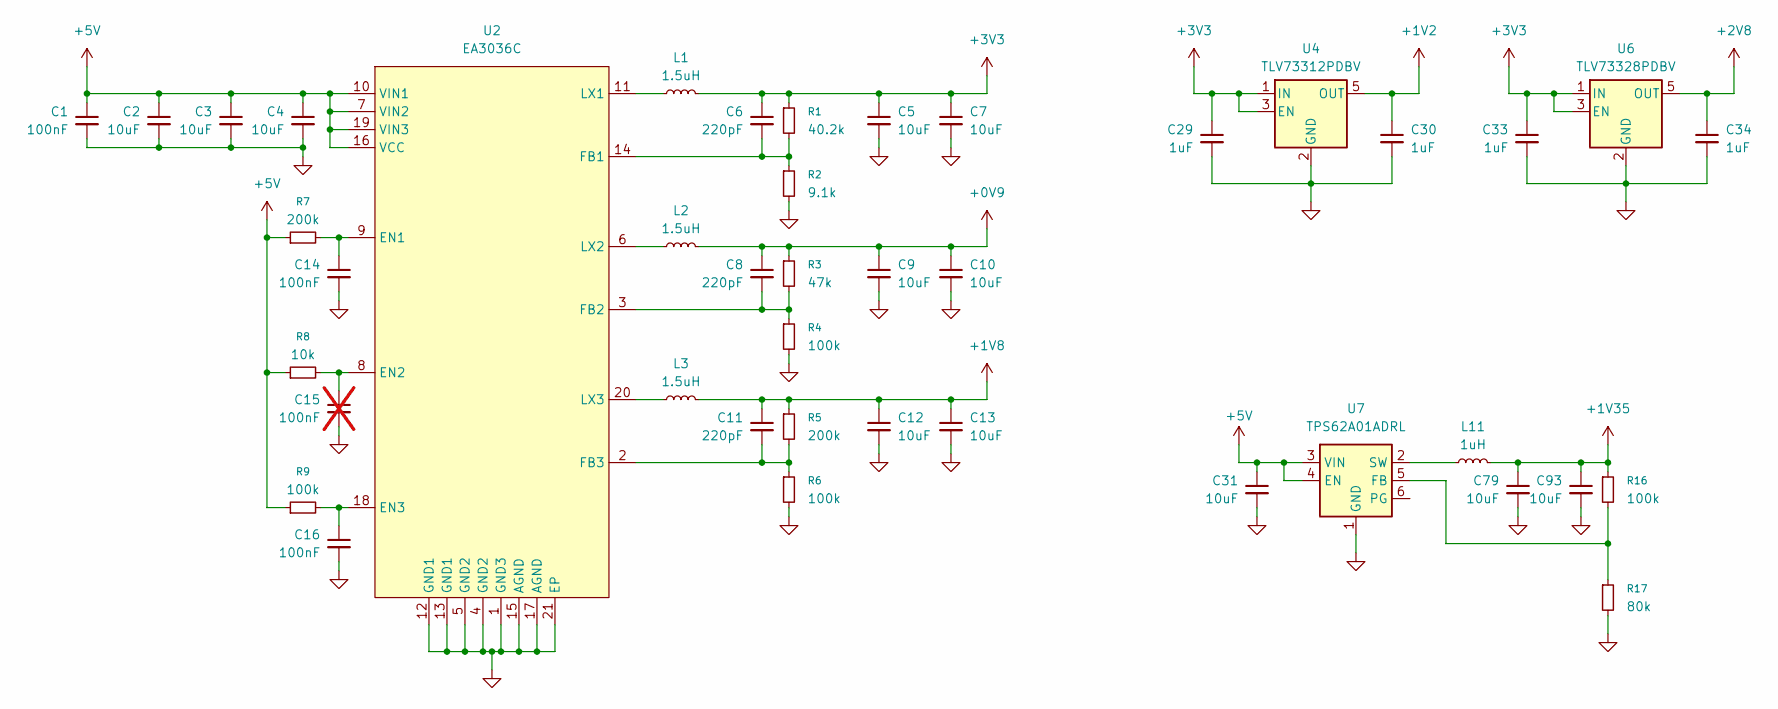
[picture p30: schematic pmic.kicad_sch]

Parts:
C1, C14, C16: 100nF; C_0402_1005Metric; MPN CL05B104KP5VPNC
C2, C3, C4, C5, C7, C9, C10, C12, C13, C31, C79, C93: 10uF; C_0402_1005Metric; MPN GRM155R60J106ME05D
C6, C8, C11: 220pF; C_0402_1005Metric; MPN GCM1555C1H221JA16D
C15: 100nF; C_0402_1005Metric; MPN CL05B104KP5VPNC; not fitted
C29, C30, C33, C34: 1uF; C_0402_1005Metric; MPN C0402C105K9PACTU
L1, L2, L3: 1.5uH; L_1008_2520Metric; MPN DFE252012P-1R5M=P2
L11: 1uH; L_1008_2520Metric; MPN DFE252012P-1R0M=P2
R1: 40.2k; R_0402_1005Metric; MPN RC0402FR-0740K2L
R2: 9.1k; R_0402_1005Metric; MPN RC0402FR-079K1L
R3: 47k; R_0402_1005Metric; MPN RC0402FR-0747KL
R4, R6, R9: 100k; R_0402_1005Metric; MPN RC0402FR-07100KL
R5, R7: 200k; R_0402_1005Metric; MPN RC0402FR-07200KL
R8: 10k; R_0402_1005Metric; MPN RC0402FR-0710KL
R16: 100k; R_0402_1005Metric
R17: 80k; R_0402_1005Metric
U2: EA3036C; QFN-20-1EP_3x3mm_P0.4mm_EP1.65x1.65mm; MPN EA3036CQBR
U4: TLV73312PDBV; SOT-23-5; MPN TLV73312PDBV
U6: TLV73328PDBV; SOT-23-5; MPN TLV73328PDBVR
U7: TPS62A01ADRL; SOT-563

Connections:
+0V9: C8.1, C9.1, C10.1, L2.2, R3.1; also elsewhere on the board
+1V2: C30.1, U4.5 (OUT); also elsewhere on the board
+1V8: C11.1, C12.1, C13.1, L3.2, R5.1; also elsewhere on the board
+1V35: C79.1, C93.1, L11.2, R16.1; also elsewhere on the board
+2V8: C34.1, U6.5 (OUT); also elsewhere on the board
+3V3: C5.1, C6.1, C7.1, C29.1, C33.1, L1.2, R1.1, U4.1 (IN), U4.3 (EN), U6.1 (IN), U6.3 (EN); also elsewhere on the board
+5V: C1.1, C2.1, C3.1, C4.1, C31.1, R7.1, R8.1, R9.1, U2.7 (VIN2), U2.10 (VIN1), U2.16 (VCC), U2.19 (VIN3), U7.3 (VIN), U7.4 (EN); also elsewhere on the board
GND: C1.2, C2.2, C3.2, C4.2, C5.2, C7.2, C9.2, C10.2, C12.2, C13.2, C14.2, C15.2, C16.2, C29.2, C30.2, C31.2, C33.2, C34.2, C79.2, C93.2, R2.2, R4.2, R6.2, R17.2, U2.1 (GND3), U2.4 (GND2), U2.5 (GND2), U2.12 (GND1), U2.13 (GND1), U2.15 (AGND), U2.17 (AGND), U2.21 (EP), U4.2 (GND), U6.2 (GND), U7.1 (GND); also elsewhere on the board
unnamed: C14.1, R7.2, U2.9 (EN1)
unnamed: C15.1, R8.2, U2.8 (EN2)
unnamed: C16.1, R9.2, U2.18 (EN3)
unnamed: C6.2, R1.2, R2.1, U2.14 (FB1)
unnamed: C8.2, R3.2, R4.1, U2.3 (FB2)
unnamed: C11.2, R5.2, R6.1, U2.2 (FB3)
unnamed: L1.1, U2.11 (LX1)
unnamed: L2.1, U2.6 (LX2)
unnamed: L3.1, U2.20 (LX3)
unnamed: R16.2, R17.1, U7.5 (FB)
unnamed: L11.1, U7.2 (SW)


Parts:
C73, C74, C82: NC; C_0402_1005Metric; not fitted
C81, C83, C84, C85, C92: 10uF; C_0603_1608Metric; MPN LMK107BBJ106MALT
J3: Conn_Coaxial; U.FL_Hirose_U.FL-R-SMT-1_Vertical; MPN HRS U.FL-R-SMT-1(80)
L10: 120R@100MHz; L_0603_1608Metric; MPN BLM18KG121TN1D
R25: 10K; R_0402_1005Metric; not fitted
R29, R33: 1k; R_0402_1005Metric; MPN RC0402JR-071KL
R30: 0R; R_0402_1005Metric; MPN RC0402FR-070RL
R31: 100K; R_0402_1005Metric; not fitted
R34: 100k; R_0402_1005Metric; MPN RC0402FR-13100KL
R35: 10k; R_0402_1005Metric; MPN RC0402JR-0710KL
R36: 0R; R_0402_1005Metric; not fitted
RN3, RN4: 10k; R_Array_Convex_4x0402; MPN 4D02WGJ0103TCE
U10: RTL8723DS; RTL8723; MPN RTL8723DS

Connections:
+3.3VA: C81.1, C83.1, C85.1, C92.1, L10.2, R34.2, R35.2, RN3.5 (R4.2), RN3.6 (R3.2), RN3.7 (R2.2), RN3.8 (R1.2), RN4.5 (R4.2), RN4.6 (R3.2), RN4.7 (R2.2), RN4.8 (R1.2), U10.9 (VBAT), U10.22 (VDD_IO)
+3V3: C84.1, L10.1; also elsewhere on the board
/MPU/BT_HOST_WAKE: U10.7 (BT_HOST_WAKE); also elsewhere on the board
/MPU/BT_LPO: R36.1; also elsewhere on the board
/MPU/BT_WAKE: R31.2, U10.6 (BT_WAKE); also elsewhere on the board
/MPU/SDMMC2.CLK: RN4.3 (R3.1), U10.17 (SD_CLK); also elsewhere on the board
/MPU/SDMMC2.CMD: RN4.4 (R4.1), U10.16 (SD_CMD); also elsewhere on the board
/MPU/SDMMC2.D0: RN4.2 (R2.1), U10.18 (SD_D0); also elsewhere on the board
/MPU/SDMMC2.D1: RN4.1 (R1.1), U10.19 (SD_D1); also elsewhere on the board
/MPU/SDMMC2.D2: RN3.2 (R2.1), U10.14 (SD_D2); also elsewhere on the board
/MPU/SDMMC2.D3: RN3.1 (R1.1), U10.15 (SD_D3); also elsewhere on the board
/MPU/UART1.RXD: R29.1; also elsewhere on the board
/MPU/UART1.TXD: R33.1; also elsewhere on the board
/MPU/UART1.~CTS: U10.41 (UART_RTS_N); also elsewhere on the board
/MPU/UART1.~RTS: U10.44 (UART_CTS_N); also elsewhere on the board
/MPU/WL_HOST_WAKE: RN3.3 (R3.1), U10.13 (WL_HOST_WAKE); also elsewhere on the board
/MPU/WL_REG_ON: R25.2, RN3.4 (R4.1), U10.12 (WL_REG_ON); also elsewhere on the board
/MPU/~BT_RST: C82.1, R34.1, U10.34 (BT_RST_N); also elsewhere on the board
/RTL8723/LPO: R35.1, R36.2, U10.24 (LPO)
GND: C73.2, C74.2, C81.2, C82.2, C83.2, C84.2, C85.2, C92.2, J3.2 (Ext), R25.1, R31.1, U10.1 (GND), U10.3 (GND), U10.20 (GND), U10.31 (GND), U10.33 (GND), U10.36 (GND); also elsewhere on the board
unnamed: C73.1, J3.1 (In), R30.1
unnamed: R33.2, U10.43 (UART_RXD)
unnamed: R29.2, U10.42 (UART_TXD)
unnamed: C74.1, R30.2, U10.2 (WIFI/BT_ANT)

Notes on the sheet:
Check L5 package and PN it was MMZ2012R121AT000 before
RTL8723DS - Populate B and D XR829 - Populate A and C



Board: 4 copper layers, 117.5 x 30.0 mm, 179 parts (120 on the bottom side), 102 nets.

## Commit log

2026-06-30 Initial commit.
    [mpu.kicad_sch, pmic.kicad_sch, wingcam_ee.kicad_pcb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]
2026-07-21 Schematic finished
    [HR911105A.step, M12_lens_holder.STEP, QFN-88P35_EP.step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]
2026-07-23 Worked on the routing
    [4reel_ee.kicad_pcb, 4reel_ee.kicad_sch, flash.kicad_sch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]
2026-07-25 Worked on the routing.
    [4reel_ee.kicad_pcb, 4reel_ee.kicad_sch, mpu.kicad_sch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]
2026-07-26 Finished initial rough layout.
    [4reel_ee.kicad_pcb, 4reel_ee.kicad_sch]
2026-08-19 R0.1 release.
    [4reel_ee-B_Cu.gbl, 4reel_ee-B_Fab.gbr, 4reel_ee-B_Mask.gbs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]
2026-09-02 Correctd RV1103B part.
    [4reel_ee.kicad_sch]
2026-09-09 Initial schematic, routing finished for RV1106 based design.
    [4reel_ee.kicad_pcb, 4reel_ee.kicad_sch, QFN-128_L12.3-W12.3-P0.35-TL-EP7.0-1.step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]
2026-09-18 Added working os build system for rv1103 board.
    [genimage.cfg]
2026-09-19 Added code to label LEDs and turn on LED1 on boot.
2026-09-19 Added some notes on next board spin.
2026-09-19 Create an ext4 fs after the fat32 for persistance storage, and pulled in and tested the camera driver etc.
    [genimage.cfg]
2026-09-19 Enabled accelerometer driver, enabled ethernet, enabled spi flash, USB (virtual serial port). All tested and working.
2026-09-19 Restored the old rv1103 board (gave it it's own folder) and gave the rv1106 board it's old folder.
    [4reel_ee-B_Cu.gbl, 4reel_ee-B_Fab.gbr, 4reel_ee-B_Mask.gbs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]
2026-09-21 Enable dropbear + dnsmasq, device now comes up as ethernet device you can ssh into.
2026-09-25 Added proper lens mount / hole size.
    [4reel_ee.kicad_pcb, Arducam_U0756.step]
2026-09-25 Added web dashboard, implemented hardware SAD using Rockchip RVE, kernel patches for camera rotation, build config.
2026-10-02 Added stuff for open source
    [4reel_ee.kicad_sch]
2026-10-04 Changed LED resistors size and thicken up 0.9V trace.
    [4reel_ee.kicad_pcb, mpu.kicad_sch]

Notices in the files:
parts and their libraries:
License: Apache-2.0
